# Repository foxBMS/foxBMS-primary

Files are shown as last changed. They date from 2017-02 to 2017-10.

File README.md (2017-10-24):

# foxBMS 

foxBMS is a free, open and flexible development environment to design battery
management systems. It is the first modular open source BMS development
platform.

## foxBMS Project Setup
The foxBMS project consists of several repositories.

The foxConda-installer repository contains the installer for the foxConda
environment. This environment provides all the tools necessary to generate the
documentation, compile the code for the MCUs and flash the generated binaries on
the MCUs (e.g., Python, git, GCC).

The starting point to get foxBMS is the foxBMS-setup
repository (https://github.com/foxBMS/foxBMS-setup), which contains
the general setup files for the foxBMS project. It includes a setup script
(bootstrap.py) which clones all the other needed repositories. The needed
documentation will be generated automatically after these repositories have been
cloned. The generated documentation is found in the directory ./build.
After the bootstrap step, the top project directory (foxBMS-setup) structure
looks like this:

 - foxBMS-setup <dir>
  - .git <dir> *
  - build <dir>
  - foxBMS-documentation <dir>
  - foxBMS-hardware <dir>
  - foxBMS-primary <dir>
  - foxBMS-secondary <dir>
  - foxBMS-tools <dir>
  - FreeRTOS <dir>
  - hal <dir>
  - .gitignore <file> *
  - bootstrap.py <file>
  - build.py <file>
  - CHANGELOG.md <file>
  - clean.py <file>
  - LICENSE.md <file>
  - README.md <file>
  - wscript <file>

* Directories and files with starting full stop are hidden in Windows in default
configuration.

There is a help available by running "python bootstrap.py -h".

## foxBMS Repositories

The foxConda-installer and foxBMS-setup repositories have already been described.

foxBMS is made out of two Microcontroller Units (MCU), named primary and
secondary. The C code for the primary MCU is found in the repository
foxBMS-primary (https://github.com/foxBMS/foxBMS-primary). The C code for the
secondary MCU is found in the repository foxBMS-secondary
(https://github.com/foxBMS/foxBMS-secondary). The Doxygen documentation is
generated from these sources into ./build/primary/doxygen/html and
./build/secondary/doxygen/html respectively. The main file is in both cases
index.html.

The layout and schematic files for the foxBMS hardware are found in the
foxBMS-hardware repository (https://github.com/foxBMS/foxBMS-hardware).

The Hardware Abstraction Layer (hal) for foxBMS is found in the hal-repository
(https://github.com/foxBMS/hal.) The real time operating system (FreeRTOS) for
foxBMS is found in the FreeRTOS-repository (https://github.com/foxBMS/FreeRTOS.)

The tools needed for foxBMS are in the foxBMS-tools-repository
(https://github.com/foxBMS/foxBMS-tools.)

The general documentation files for the foxBMS project are found in the
foxBMS-documentation repository
(https://github.com/foxBMS/foxBMS-documentation). The sphinx documentation is
found in foxBMS-documentation/doc/sphinx while the Doxygen documentation
configuration is found in foxBMS-documentation/doc/doxygen. The Doxygen
documentation itself is found in the software sources of the primary and
secondary microcontroller. The general documentation, rendered from the sphinx
sources is found in ./build/sphinx/foxBMS-documentation/doc/sphinx/html. The
main file is index.html

A generated version of the Sphinx documentation can be found at
http://foxbms.readthedocs.io/. It explains the structure of the
foxBMS hardware, how to install the foxConda environment and how to use foxConda
to compile and flash the sources.

## Building the Sources
For building the software, open a shell and type "python build.py -h". All
available build options will be displayed. The top build directory is ./build.

## Cleaning the ./build-Directory
For cleaning instructions open a shell and type "python clean.py -h". All
available cleaning options will be displayed.

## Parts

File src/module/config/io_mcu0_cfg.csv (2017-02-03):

Package Pin | PortXpinY | Signalname | Group | Comment | Interface
41 | PA1 | MCU_0_ADC_CH_4 | # ADCs
56 | PB0 | MCU_0_ADC_CH_2 | # ADCs
57 | PB1 | MCU_0_ADC_CH_3 | # ADCs
54 | PC4 | MCU_0_ADC_CH_0 | # ADCs
55 | PC5 | MCU_0_ADC_CH_1 | # ADCs
47 | PA3 | MCU_0_BENDER_PWM | # Bender
43 | PH2 | MCU_0_BENDER_SUPPLY_ENABLE | # Bender
46 | PH5 | MCU_0_BENDER_OK | # Bender
119 | PA8 | MCU_0_CONTACTOR_4_CONTROL | # Contactors' Controll and Feedback Pins
120 | PA9 | MCU_0_CONTACTOR_3_CONTROL | # Contactors' Controll and Feedback Pins
164 | PB6 | MCU_0_CONTACTOR_7_FEEDBACK | # Contactors' Controll and Feedback Pins
139 | PC10 | MCU_0_CONTACTOR_6_CONTROL | # Contactors' Controll and Feedback Pins
140 | PC11 | MCU_0_CONTACTOR_6_FEEDBACK | # Contactors' Controll and Feedback Pins
115 | PC6 | MCU_0_CONTACTOR_3_FEEDBACK | # Contactors' Controll and Feedback Pins
116 | PC7 | MCU_0_CONTACTOR_4_FEEDBACK | # Contactors' Controll and Feedback Pins
117 | PC8 | MCU_0_CONTACTOR_5_FEEDBACK | # Contactors' Controll and Feedback Pins
118 | PC9 | MCU_0_CONTACTOR_5_CONTROL | # Contactors' Controll and Feedback Pins
144 | PD2 | MCU_0_CONTACTOR_7_CONTROL | # Contactors' Controll and Feedback Pins
146 | PD4 | MCU_0_INTERLOCK_CONTROL | # Contactors' Controll and Feedback Pins
147 | PD5 | MCU_0_INTERLOCK_FEEDBACK | # Contactors' Controll and Feedback Pins
128 | PH13 | MCU_0_CONTACTOR_0_FEEDBACK | # Contactors' Controll and Feedback Pins
129 | PH14 | MCU_0_CONTACTOR_1_FEEDBACK | # Contactors' Controll and Feedback Pins
130 | PH15 | MCU_0_CONTACTOR_2_FEEDBACK | # Contactors' Controll and Feedback Pins
44 | PH3 | MCU_0_CONTACTOR_8_CONTROL | # Contactors' Controll and Feedback Pins
45 | PH4 | MCU_0_CONTACTOR_8_FEEDBACK | # Contactors' Controll and Feedback Pins
131 | PI0 | MCU_0_CONTACTOR_2_CONTROL | # Contactors' Controll and Feedback Pins
132 | PI1 | MCU_0_CONTACTOR_1_CONTROL | # Contactors' Controll and Feedback Pins
133 | PI2 | MCU_0_CONTACTOR_0_CONTROL | # Contactors' Controll and Feedback Pins
33 | PC1 | MCU_0_SDCARD_SUPPLY_CONTROL | # Data Storage SPI and Supply
155 | PG12 | MCU_0_DATA_STORAGE_SPI_MISO | # Data Storage SPI and Supply
156 | PG13 | MCU_0_DATA_STORAGE_SPI_SCK | # Data Storage SPI and Supply
157 | PG14 | MCU_0_DATA_STORAGE_SPI_MOSI | # Data Storage SPI and Supply
7 | PI8 | MCU_0_DATA_STORAGE_EEPROM_SPI_NSS | # Data Storage SPI and Supply
11 | PI9 | MCU_0_DATA_STORAGE_SCCARD_SPI_NSS | # Data Storage SPI and Supply
34 | PC2 | MCU_0_DEBUG_LED_1 | # Debug LEDs
35 | PC3 | MCU_0_DEBUG_LED_0 | # Debug LEDs
32 | PC0 | MCU_0_FMC_RAM_SDNWE | # Flexible Memory Controller
142 | PD0 | MCU_0_FMC_RAM_D2 | # Flexible Memory Controller
143 | PD1 | MCU_0_FMC_RAM_D3 | # Flexible Memory Controller
98 | PD10 | MCU_0_FMC_RAM_D15 | # Flexible Memory Controller
104 | PD14 | MCU_0_FMC_RAM_D0 | # Flexible Memory Controller
105 | PD15 | MCU_0_FMC_RAM_D1 | # Flexible Memory Controller
96 | PD8 | MCU_0_FMC_RAM_D13 | # Flexible Memory Controller
97 | PD9 | MCU_0_FMC_RAM_D14 | # Flexible Memory Controller
169 | PE0 | MCU_0_FMC_RAM_NBL0 | # Flexible Memory Controller
170 | PE1 | MCU_0_FMC_RAM_NBL1 | # Flexible Memory Controller
73 | PE10 | MCU_0_FMC_RAM_D7 | # Flexible Memory Controller
74 | PE11 | MCU_0_FMC_RAM_D8 | # Flexible Memory Controller
75 | PE12 | MCU_0_FMC_RAM_D9 | # Flexible Memory Controller
76 | PE13 | MCU_0_FMC_RAM_D10 | # Flexible Memory Controller
77 | PE14 | MCU_0_FMC_RAM_D11 | # Flexible Memory Controller
78 | PE15 | MCU_0_FMC_RAM_D12 | # Flexible Memory Controller
68 | PE7 | MCU_0_FMC_RAM_D4 | # Flexible Memory Controller
69 | PE8 | MCU_0_FMC_RAM_D5 | # Flexible Memory Controller
70 | PE9 | MCU_0_FMC_RAM_D6 | # Flexible Memory Controller
16 | PF0 | MCU_0_FMC_RAM_A0 | # Flexible Memory Controller
17 | PF1 | MCU_0_FMC_RAM_A1 | # Flexible Memory Controller
59 | PF11 | MCU_0_FMC_RAM_SDNRAS | # Flexible Memory Controller
60 | PF12 | MCU_0_FMC_RAM_A6 | # Flexible Memory Controller
63 | PF13 | MCU_0_FMC_RAM_A7 | # Flexible Memory Controller
64 | PF14 | MCU_0_FMC_RAM_A8 | # Flexible Memory Controller
65 | PF15 | MCU_0_FMC_RAM_A9 | # Flexible Memory Controller
18 | PF2 | MCU_0_FMC_RAM_A2 | # Flexible Memory Controller
19 | PF3 | MCU_0_FMC_RAM_A3 | # Flexible Memory Controller
20 | PF4 | MCU_0_FMC_RAM_A4 | # Flexible Memory Controller
21 | PF5 | MCU_0_FMC_RAM_A5 | # Flexible Memory Controller
66 | PG0 | MCU_0_FMC_RAM_A10 | # Flexible Memory Controller
67 | PG1 | MCU_0_FMC_RAM_A11 | # Flexible Memory Controller
160 | PG15 | MCU_0_FMC_RAM_SDNCAS | # Flexible Memory Controller
108 | PG4 | MCU_0_FMC_RAM_BA0 | # Flexible Memory Controller
109 | PG5 | MCU_0_FMC_RAM_BA1 | # Flexible Memory Controller
112 | PG8 | MCU_0_FMC_RAM_SDCLK | # Flexible Memory Controller
83 | PH6 | MCU_0_FMC_RAM_SDNE1 | # Flexible Memory Controller
84 | PH7 | MCU_0_FMC_RAM_SDCKE1 | # Flexible Memory Controller
14 | GND |  | # Ground Pins
22 | GND |  | # Ground Pins
61 | GND |  | # Ground Pins
71 | GND |  | # Ground Pins
90 | GND |  | # Ground Pins
102 | GND |  | # Ground Pins
113 | GND |  | # Ground Pins
126 | GND |  | # Ground Pins
135 | GND |  | # Ground Pins
148 | GND |  | # Ground Pins
158 | GND |  | # Ground Pins
121 | PA10 | MCU_0_BMS_INTERFACE_GPIO_0 | # Interfaces
122 | PA11 | MCU_0_BMS_INTERFACE_GPIO_1 | # Interfaces
123 | PA12 | MCU_0_BMS_INTERFACE_GPIO_2 | # Interfaces
42 | PA2 | MCU_0_RS485_TX | # Interfaces
50 | PA4 | MCU_0_BMS_INTERFACE_SPI_NSS | # Interfaces
51 | PA5 | MCU_0_BMS_INTERFACE_SPI_SCK | # Interfaces
52 | PA6 | MCU_0_BMS_INTERFACE_SPI_MISO | # Interfaces
53 | PA7 | MCU_0_BMS_INTERFACE_SPI_MOSI | # Interfaces
79 | PB10 | MCU_0_FTDI_TX | # Interfaces
80 | PB11 | MCU_0_FTDI_RX | # Interfaces
92 | PB12 | MCU_0_TO_MCU_1_INTERFACE_SPI_NSS | # Interfaces
93 | PB13 | MCU_0_CAN_0_TX | # Interfaces | CAN bootable (CAN2)
94 | PB14 | MCU_0_TO_MCU_1_INTERFACE_SPI_MISO | # Interfaces
95 | PB15 | MCU_0_TO_MCU_1_INTERFACE_SPI_MOSI | # Interfaces
162 | PB4 | MCU_0_BMS_INTERFACE_GPIO_3 | # Interfaces
163 | PB5 | MCU_0_CAN_0_RX | # Interfaces
165 | PB7 | MCU_0_CAN_1_TRANS_STANDBY_CONTROL | # Interfaces
167 | PB8 | MCU_0_CAN_1_RX | # Interfaces
168 | PB9 | MCU_0_CAN_1_TX | # Interfaces
141 | PC12 | MCU_0_CAN_0_TRANS_STANDBY_CONTROL | # Interfaces
145 | PD3 | MCU_0_TO_MCU_1_INTERFACE_SPI_SCK | # Interfaces
150 | PD6 | MCU_0_RS845_RX | # Interfaces
24 | PF6 | MCU_0_TO_FPGA_INTERFACE_SPI_NSS | # Interfaces
25 | PF7 | MCU_0_TO_FPGA_INTERFACE_SPI_SCK | # Interfaces
26 | PF8 | MCU_0_TO_FPGA_INTERFACE_SPI_MISO | # Interfaces
27 | PF9 | MCU_0_TO_FPGA_INTERFACE_SPI_MOSI | # Interfaces
106 | PG2 | MCU_0_RS485_NRE | # Interfaces
107 | PG3 | MCU_0_RS485_DE | # Interfaces
99 | PD11 | MCU_0_ISONOC_5_CONTROL | # Isolated In- and Outputs
100 | PD12 | MCU_0_ISO_GPIO_OUT_0 | # Isolated In- and Outputs
101 | PD13 | MCU_0_ISO_GPIO_OUT_1 | # Isolated In- and Outputs
153 | PG10 | MCU_0_ISO_GPIO_IN_1 | # Isolated In- and Outputs
154 | PG11 | MCU_0_ISO_GPIO_OUT_2 | # Isolated In- and Outputs
152 | PG9 | MCU_0_ISO_GPIO_IN_0 | # Isolated In- and Outputs
87 | PH10 | MCU_0_ISONOC_2_CONTROL | # Isolated In- and Outputs
88 | PH11 | MCU_0_ISONOC_3_CONTROL | # Isolated In- and Outputs
89 | PH12 | MCU_0_ISONOC_4_CONTROL | # Isolated In- and Outputs
85 | PH8 | MCU_0_ISONOC_0_CONTROL | # Isolated In- and Outputs
86 | PH9 | MCU_0_ISONOC_1_CONTROL | # Isolated In- and Outputs
173 | PI4 | MCU_0_ISO_GPIO_OUT_3 | # Isolated In- and Outputs
174 | PI5 | MCU_0_ISO_GPIO_IN_2 | # Isolated In- and Outputs
175 | PI6 | MCU_0_ISO_GPIO_IN_3 | # Isolated In- and Outputs
8 | PC13 | MCU_0_RTC_ALARM_OUT | # Pins free to be used
151 | PD7 |  | # Pins free to be used
28 | PF10 |  | # Pins free to be used
110 | PG6 |  | # Pins free to be used
111 | PG7 |  | # Pins free to be used
12 | PI10 |  | # Pins free to be used
13 | PI11 |  | # Pins free to be used
134 | PI3 |  | # Pins free to be used
176 | PI7 |  | # Pins free to be used
166 | BOOT0 |  | # Special Pins | Boot0
48 | BYPASS_REG |  | # Special Pins | BYPASS_REG
37 | GNDA |  | # Special Pins | GNDA
31 | NRST |  | # Special Pins | RESET
40 | PA0 |  | # Special Pins | Wakeup
124 | PA13 |  | # Special Pins | SWDIO
137 | PA14 |  | # Special Pins | SWCLK
138 | PA15 |  | # Special Pins | TDI
58 | PB2 |  | # Special Pins | BOOT1
161 | PB3 |  | # Special Pins | SWO
9 | PC14 |  | # Special Pins | RTC_XTAL
10 | PC15 |  | # Special Pins | RTC_XTAL
171 | PDR_ON |  | # Special Pins | PDR_ON
29 | PH0 |  | # Special Pins | XTAL
30 | PH1 |  | # Special Pins | XTAL
6 | VBATT |  | # Special Pins | Battery
81 | VCAP_1 |  | # Special Pins | VCAP_1
125 | VCAP_2 |  | # Special Pins | VCAP_2
39 | VCCA |  | # Special Pins | VCCA
38 | VREF+ |  | # Special Pins | VREF 2.5V
15 | VCC |  | # Supply Pins
23 | VCC |  | # Supply Pins
36 | VCC |  | # Supply Pins
49 | VCC |  | # Supply Pins
62 | VCC |  | # Supply Pins
72 | VCC |  | # Supply Pins
82 | VCC |  | # Supply Pins
91 | VCC |  | # Supply Pins
103 | VCC |  | # Supply Pins
114 | VCC |  | # Supply Pins
127 | VCC |  | # Supply Pins
136 | VCC |  | # Supply Pins
149 | VCC |  | # Supply Pins
159 | VCC |  | # Supply Pins
172 | VCC |  | # Supply Pins
1 | PE2 | MCU_0_TRACECLK | # Trace
2 | PE3 | MCU_0_TRACED0 | # Trace
3 | PE4 | MCU_0_TRACED1 | # Trace
4 | PE5 | MCU_0_TRACED2 | # Trace
5 | PE6 | MCU_0_TRACED3 | # Trace

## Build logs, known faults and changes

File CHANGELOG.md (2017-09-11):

# foxBMS Change Log

## Release 0.5.2

Release notes:
We fixed a bug in the ltc driver, leading to a non-functional temperature 
sensing for foxBMS Slave Hardware version 1.xx. The slave version is 
configuration for the primary MCU in foxBMS-primary\src\module\config\ltc_cfg.h
by the define SLAVE_BOARD_VERSION and for the secondary MCU in 
foxBMS-secondary\src\module\config\ltc_cfg.h by the define SLAVE_BOARD_VERSION.
 - Set SLAVE_BOARD_VERSION to "1" if you are using version 1.xx of the foxBMS 
   Slave.
 - Set SLAVE_BOARD_VERSION to "2" if you are using version 2.xx of the foxBMS 
   Slave. Version 2.xx is the default configuration.

Changelog :
- foxBMS-primary
  - fixed LTC temperature sensing bug
- foxBMS-secondary
  - fixed LTC temperature sensing bug

## Release 0.5.1

- foxBMS-setup
  - added parameter '-u', '--update' to bootstrap.py for updating the setup
    repository.
- foxBMS-primary
  - updates for waf 1.9.13 support
  - updated module/EEPROM and migrated to module/nvmram
  - minor code adaptations and cleanup
- foxBMS-secondary
  - support for waf 1.9.13
  - minor code adaptations and cleanup
- foxbMS-tools
  - updated waf from version 1.8.12 to version 1.9.13

## Release 0.5.0

A new project structure is now used by foxBMS. The documentation is no more
contained in the embedded software sources and has its own repository. FreeRTOS
and hal have their own repository, too.
A central repository called foxBMS-setup is now used. It contains
several scripts:
 - bootstrap.py gets all the repositories needed to work with foxBMS
 - build.py is used to compile binaries and to generate the documentation
 - clean.py is used to removed the generated binaries and documentation

Release notes:

 - New project structure

 - Added support for external (SPI) EEPROM on the BMS-Master
 - Redesign of can and cansignal module to simplify the usage
 - Added support for triggered and cyclic current measurement of Isabellenhütte
   current sensor (IVT)
 - Current sensor now functions by default in non-triggered modus (no
   reprogramming needed for the sensor)

 - Updated and restructured complete documentation
 - Restructured file and folder structure for the documentation
 - Added safety and risk analysis section
 - Cleaning up of non-used files in the documentation
 - Consistency check and correction of the naming and wording used
 - Addition of the source files (e.g., Microsoft Visio diagrams) used to
   generate the figures in the documentation
 - Reformatted the licenses text formatting (no changes in the licenses
   content)
 - Updated the battery junction box (BJB) section with up-to-date components
   and parameters

## Release 0.4.4

The checksum tool is now automatically called when building binaries.
Therefore the command
    python tools/waf-1.8.12 configure build chksum
is NOT longer supported. The command to build binaries with checksum support is
    python tools/waf-1.8.12 configure build
This is the build command used in foxBMS FrontDesk, that is, FrontDesk software
is compatible with this change and now supports automatic checksum builds.

Release notes:
 - Improved checksum-feature
 - Updated copyright 2010 - 2017

## Release 0.4.3

Starting from this version, a checksum mechanism was implemented in foxBMS. If
the checksum is active and it is not computed correctly, it will prevent the
flashed program from running. Details on deactivating the checksum can be found
in the Software FAQ, in How to use and deactivate the checksum.

Release notes:
 - Important: Changed contactor configuration order in the software to match
   the labels on the front
  - Contactor 0: CONT_PLUS_MAIN
  - Contactor 1: CONT_PLUS_PRECHARGE
  - Contactor 2: CONT_MINUS_MAIN
 - Fixed an bug which could cause an unintended closing of the contactors after
   recovering from error mode
 - Increased stack size for the engine tasks to avoid stack overflow in some
   special conditions
 - Added a note in the documentation to indicate the necessity to send a
   periodic CAN message to the BMS
 - Fixed DLC of CAN message for the current sensor measurement
 - Added checksum verification for the flashed binaries
 - Updated linker script to allow integration of the checksum tool
 - Activated debug without JTAG interface via USB

## Release 0.4.2

Release notes:
 - Removed schematic files from documentation, registration needed to obtain
   the files
 - Added entries to the software FAQ

## Release 0.4.1

Release notes:

 - Corrected daisy chain connector pinout in quickstart guide
 - Corrected code for contactors, to allow using contactors without feedback
 - Corrected LTC code for reading balancing feedback
 - Quickstart restructured, with mention of the necessity to generate the HTML
   documentation

## Release 0.4.0

Beta version of foxBS that was supplied to selected partners for evaluation.

Release notes:

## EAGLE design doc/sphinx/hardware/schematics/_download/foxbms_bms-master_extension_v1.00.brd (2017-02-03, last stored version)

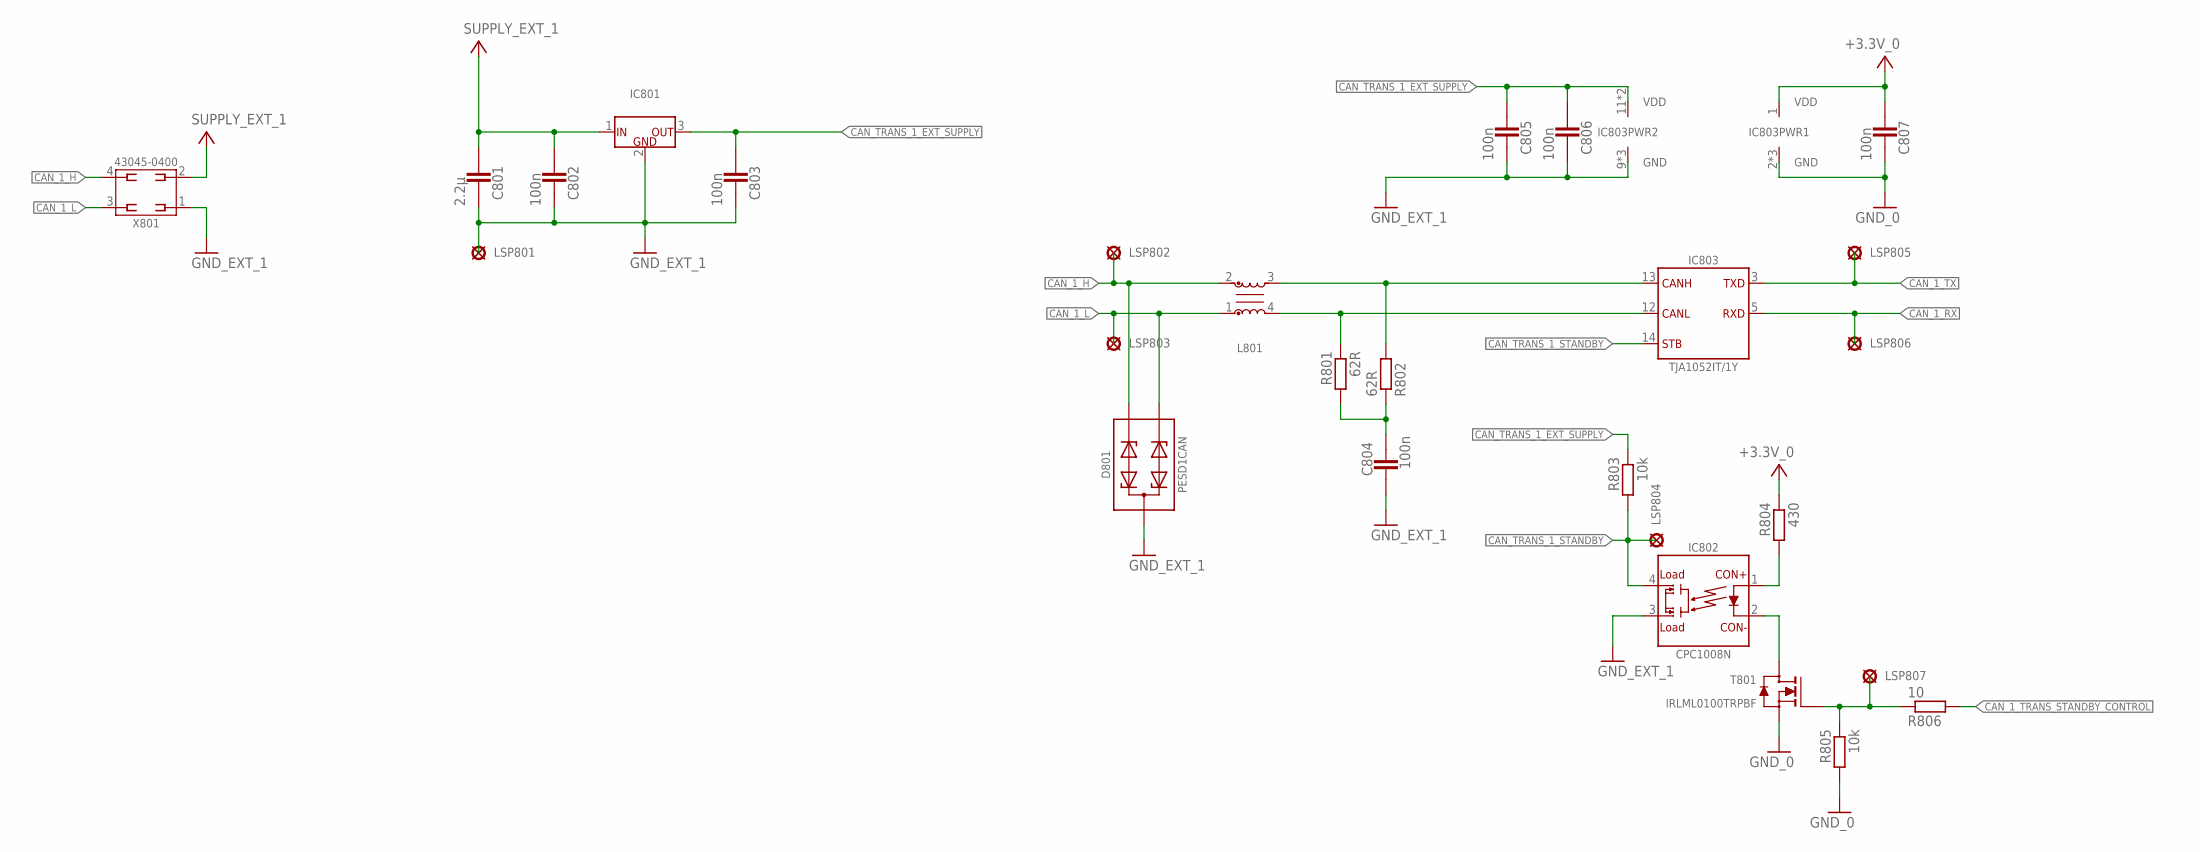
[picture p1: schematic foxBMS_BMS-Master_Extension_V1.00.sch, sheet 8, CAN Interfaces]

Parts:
C801: 2.2µ; 0603
C802, C803, C804, C805, C806, C807: 100n; 0603
D801: PESD1CAN; D_SMD_SOT23_(TO-236AB)_R_NXP_REV01
IC801: KA7805ERTF; IC_SMD_TO-252_(D-PAK)_R_FAIRCHILD_REV01
IC802: CPC1008N; K_SMD_SOP-4_R_IXYS_REV01
IC803: TJA1052IT/1Y; IC_SMD_SO16_(SOT162-1)_R_NXP_REV01
L801: B82789C0513N002; L_SMD_FILTER_HF_R_EPCOS_SIMDAD_1812_REV01
LSP801, LSP802, LSP803, LSP804, LSP805, LSP806, LSP807: PAD_2.0X1.5MM; PAD2.0X1.5MM
R801, R802: 62R; 0603
R803, R805: 10k; 0603
R804: 430; 0603
R806: 10; 0603
T801: IRLML0100TRPBF; V_SMD_SOT-23_(TO-236AB)_R_IR_REV01
X801: 43045-0400_MOLEX_4PIN; X_TH_MOLEX_43045-0400_R_REV01

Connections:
+3.3V_0: C807.2, IC803.1 (VDD), R804.1; also elsewhere on the board
CAN_1_H: D801.1, L801.2, LSP802.P$1, X801.4
CAN_1_L: D801.2, L801.1, LSP803.P$1, X801.3
CAN_1_RX: IC803.5 (RXD), LSP806.P$1; also elsewhere on the board
CAN_1_TRANS_STANDBY_CONTROL: R806.2; also elsewhere on the board
CAN_1_TX: IC803.3 (TXD), LSP805.P$1; also elsewhere on the board
CAN_L_INT1: IC803.12 (CANL), L801.4, R801.1
CAN_SPLIT1: C804.1, R801.2, R802.1
CAN_TRANS_1_EXT_SUPPLY: C803.2, C805.2, C806.2, IC801.3 (OUT), IC803.11 (VDD), IC803.16 (VDD), R803.1
CAN_TRANS_1_STANDBY: IC802.4, IC803.14 (STB), LSP804.P$1, R803.2
GND_0: C807.1, IC803.2 (GND), IC803.7 (GND), IC803.8 (GND), R805.2, T801.2 (S); also elsewhere on the board
GND_EXT_1: C801.1, C802.1, C803.1, C804.2, C805.1, C806.1, D801.3, IC801.2 (GND), IC802.3, IC803.9 (GND), IC803.10 (GND), IC803.15 (GND), LSP801.P$1, X801.1
unnamed: IC803.13 (CANH), L801.3, R802.2
unnamed: IC802.2 (CON-), T801.3 (D)
unnamed: IC802.1 (CON+), R804.2
unnamed: LSP807.P$1, R805.1, R806.1, T801.1 (G)
SUPPLY_EXT_1: C801.2, C802.2, IC801.1 (IN), X801.2

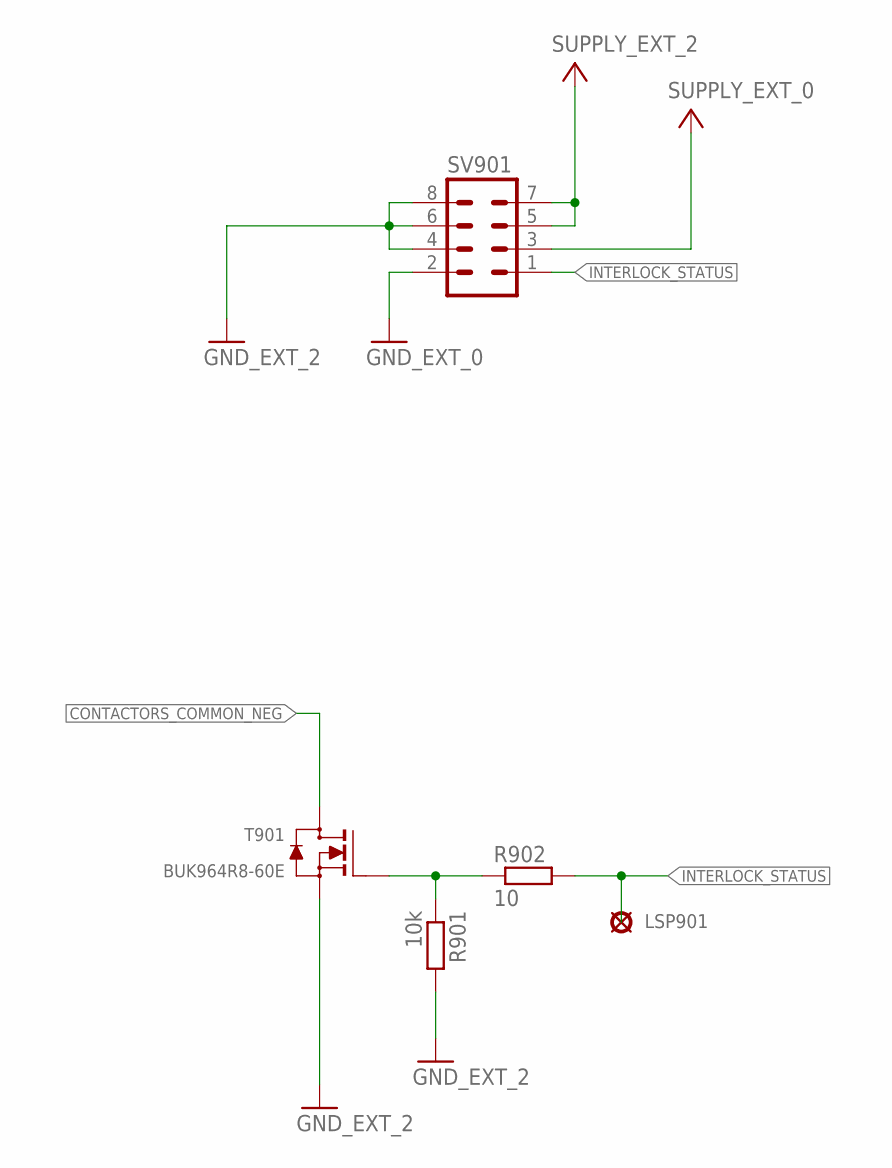
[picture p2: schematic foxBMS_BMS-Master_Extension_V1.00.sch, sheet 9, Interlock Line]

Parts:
LSP901: PAD_2.0X1.5MM; PAD2.0X1.5MM
R901: 10k; 0603
R902: 10; 0603
SV901: MA04-2
T901: BUK964R8-60E; V_SMD_TO-263_(D²PAK)_R_NXP_REV01

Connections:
CONTACTORS_COMMON_NEG: T901.2 (D); also elsewhere on the board
GND_EXT_0: SV901.2; also elsewhere on the board
GND_EXT_2: R901.2, SV901.4, SV901.6, SV901.8, T901.3 (S); also elsewhere on the board
INTERLOCK_STATUS: LSP901.P$1, R902.2, SV901.1
unnamed: R901.1, R902.1, T901.1 (G)
SUPPLY_EXT_0: SV901.3; also elsewhere on the board
SUPPLY_EXT_2: SV901.5, SV901.7; also elsewhere on the board

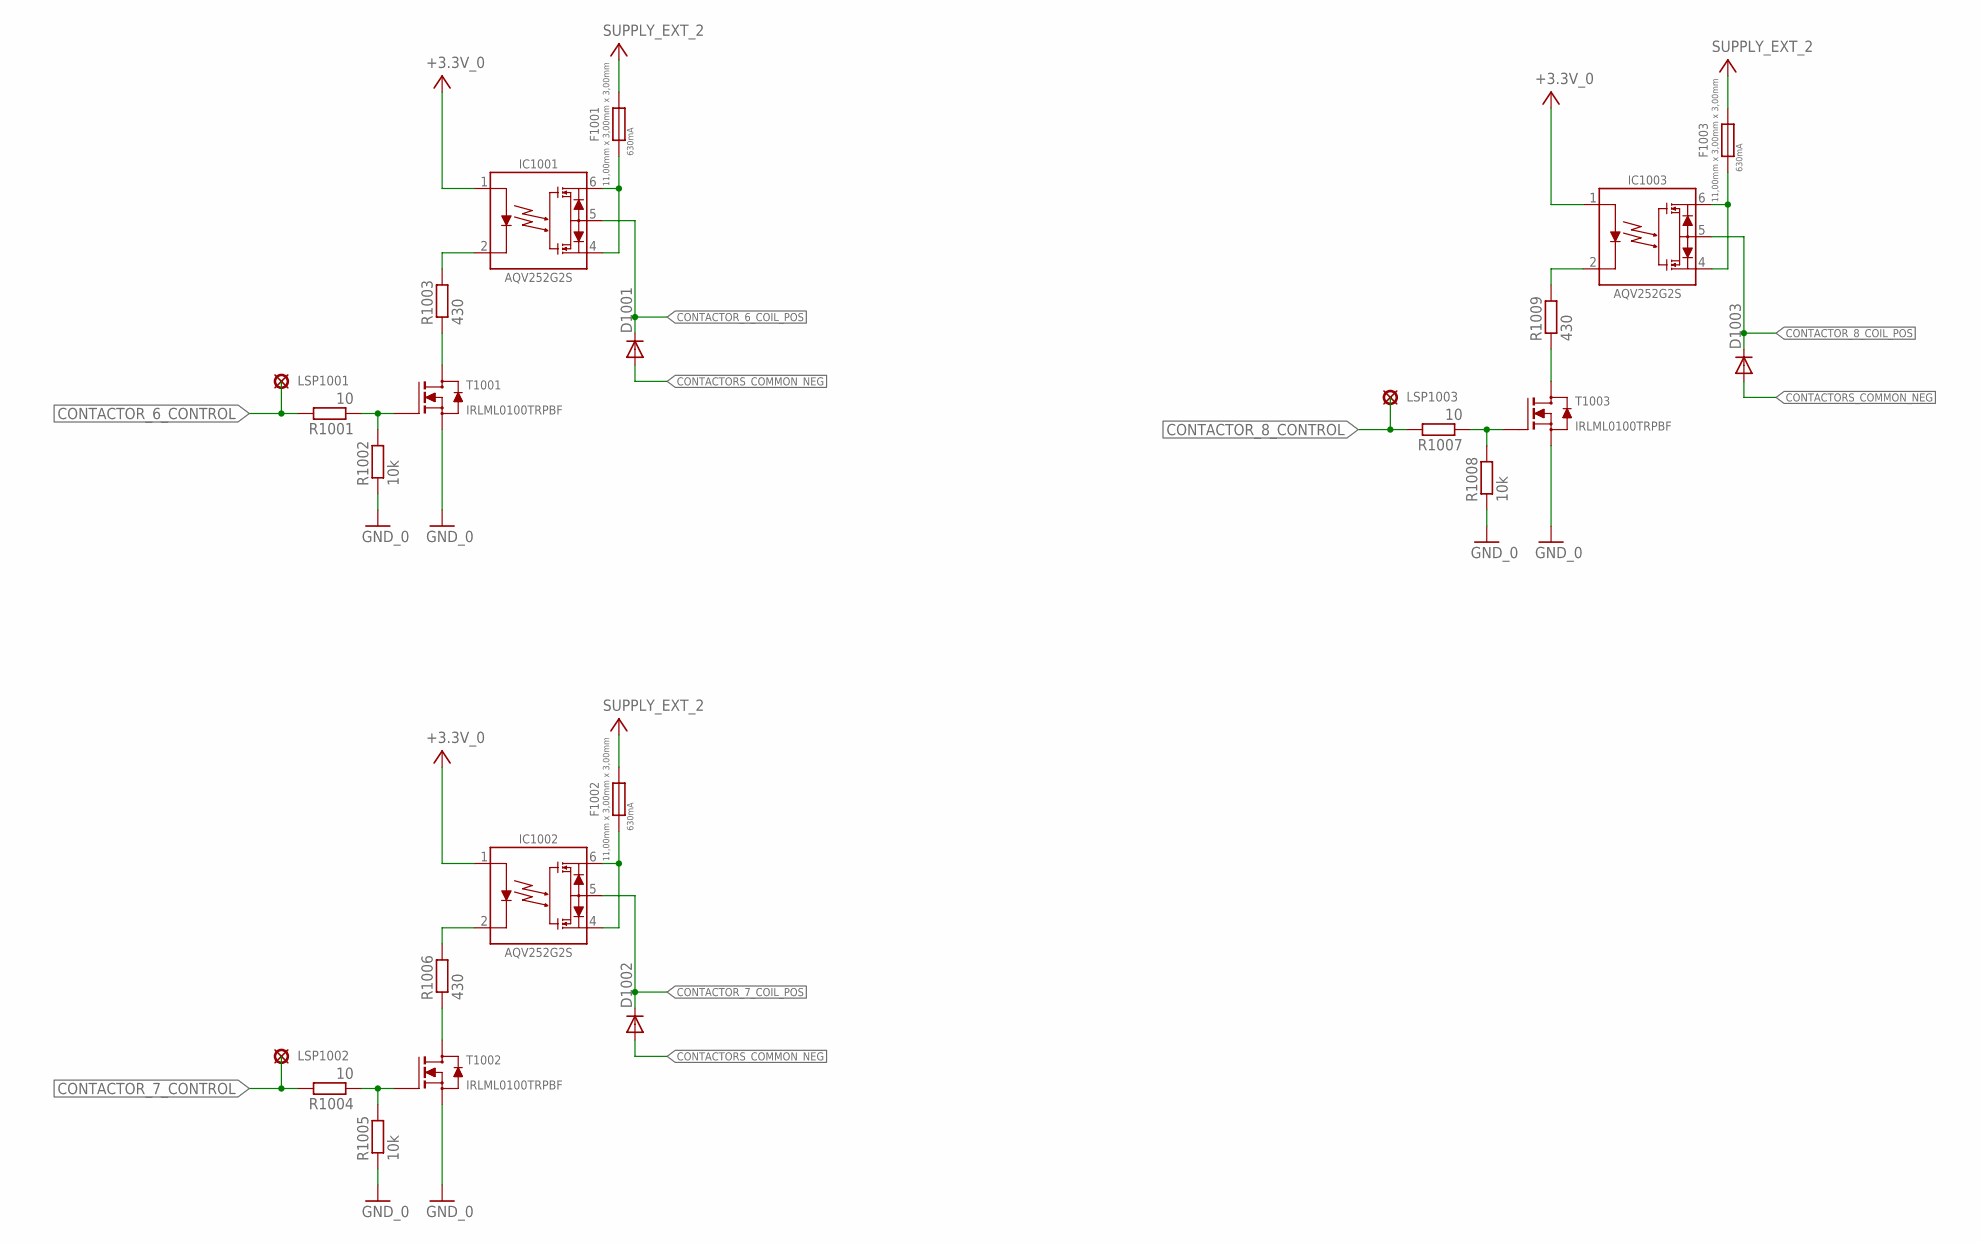
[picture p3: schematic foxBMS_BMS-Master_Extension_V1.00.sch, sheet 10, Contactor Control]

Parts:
D1001, D1002, D1003: DIODE-DO214BA; DO214BA
F1001, F1002, F1003: 630MA_UMT; F_SMD_11,00MMX3,00MMX3,00MM_(UMT)_R_SCHURTER_REV01
IC1001, IC1002, IC1003: AQV252G2S; K_SMD_SOP-6_R_PANASONIC_REV01
LSP1001, LSP1002, LSP1003: PAD_2.0X1.5MM; PAD2.0X1.5MM
R1001, R1004, R1007: 10; 0603
R1002, R1005, R1008: 10k; 0603
R1003, R1006, R1009: 430; 0603
T1001, T1002, T1003: IRLML0100TRPBF; V_SMD_SOT-23_(TO-236AB)_R_IR_REV01

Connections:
+3.3V_0: IC1001.1, IC1002.1, IC1003.1; also elsewhere on the board
CONTACTORS_COMMON_NEG: D1001.A, D1002.A, D1003.A; also elsewhere on the board
CONTACTOR_6_COIL_POS: D1001.C, IC1001.5; also elsewhere on the board
CONTACTOR_6_CONTROL: LSP1001.P$1, R1001.2; also elsewhere on the board
CONTACTOR_7_COIL_POS: D1002.C, IC1002.5; also elsewhere on the board
CONTACTOR_7_CONTROL: LSP1002.P$1, R1004.2; also elsewhere on the board
CONTACTOR_8_COIL_POS: D1003.C, IC1003.5; also elsewhere on the board
CONTACTOR_8_CONTROL: LSP1003.P$1, R1007.2; also elsewhere on the board
GND_0: R1002.1, R1005.1, R1008.1, T1001.2 (S), T1002.2 (S), T1003.2 (S); also elsewhere on the board
unnamed: R1003.1, T1001.3 (D)
unnamed: R1006.1, T1002.3 (D)
unnamed: R1009.1, T1003.3 (D)
unnamed: F1001.1, IC1001.4, IC1001.6
unnamed: F1002.1, IC1002.4, IC1002.6
unnamed: F1003.1, IC1003.4, IC1003.6
unnamed: IC1001.2, R1003.2
unnamed: R1001.1, R1002.2, T1001.1 (G)
unnamed: IC1002.2, R1006.2
unnamed: R1004.1, R1005.2, T1002.1 (G)
unnamed: IC1003.2, R1009.2
unnamed: R1007.1, R1008.2, T1003.1 (G)
SUPPLY_EXT_2: F1001.2, F1002.2, F1003.2; also elsewhere on the board

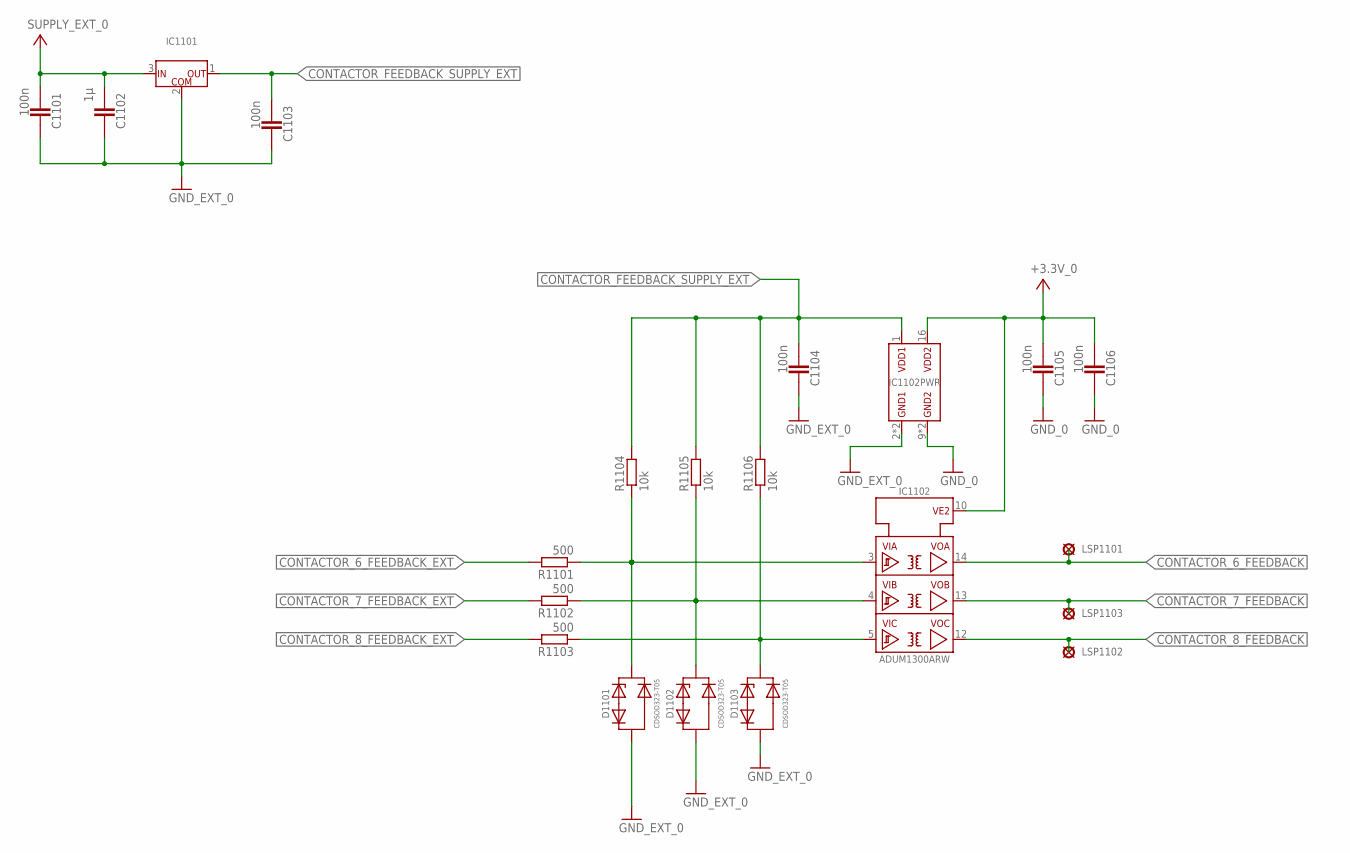
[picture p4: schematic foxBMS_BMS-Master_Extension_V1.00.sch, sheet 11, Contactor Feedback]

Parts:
C1101, C1103, C1104, C1105, C1106: 100n; 0603
C1102: 1µ; 0603
D1101, D1102, D1103: CDSOD323-T05; D_SMD_SOD323_(SC-76)_R_BOURNS_REV01
IC1101: UA78L05ACPK; IC_SMD_SOT-89_(SC-62/TO-243)_(R-PSSO-F3)_R_TI_REV01
IC1102: ADUM1300ARW; IC_SMD_SOIC-16_(JEDEC_MS-013-AA)_R_ANALOG_REV01
LSP1101, LSP1102, LSP1103: PAD_2.0X1.5MM; PAD2.0X1.5MM
R1101, R1102, R1103: 500; 0603
R1104, R1105, R1106: 10k; 0603

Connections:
+3.3V_0: C1105.1, C1106.1, IC1102.10 (VE2), IC1102.16 (VDD2); also elsewhere on the board
CONTACTOR_6_FEEDBACK: IC1102.14 (VOA), LSP1101.P$1; also elsewhere on the board
CONTACTOR_6_FEEDBACK_EXT: R1101.2; also elsewhere on the board
CONTACTOR_7_FEEDBACK: IC1102.13 (VOB), LSP1103.P$1; also elsewhere on the board
CONTACTOR_7_FEEDBACK_EXT: R1102.2; also elsewhere on the board
CONTACTOR_8_FEEDBACK: IC1102.12 (VOC), LSP1102.P$1; also elsewhere on the board
CONTACTOR_8_FEEDBACK_EXT: R1103.2; also elsewhere on the board
CONTACTOR_FEEDBACK_SUPPLY_EXT: C1103.1, C1104.1, IC1101.1 (OUT), IC1102.1 (VDD1), R1104.2, R1105.2, R1106.2
GND_0: C1105.2, C1106.2, IC1102.9 (GND2), IC1102.15 (GND2); also elsewhere on the board
GND_EXT_0: C1101.2, C1102.2, C1103.2, C1104.2, D1101.A, D1102.A, D1103.A, IC1101.2 (COM), IC1102.2 (GND1), IC1102.8 (GND1); also elsewhere on the board
unnamed: D1101.C, IC1102.3 (VIA), R1101.1, R1104.1
unnamed: D1102.C, IC1102.4 (VIB), R1102.1, R1105.1
unnamed: D1103.C, IC1102.5 (VIC), R1103.1, R1106.1
SUPPLY_EXT_0: C1101.1, C1102.1, IC1101.3 (IN); also elsewhere on the board

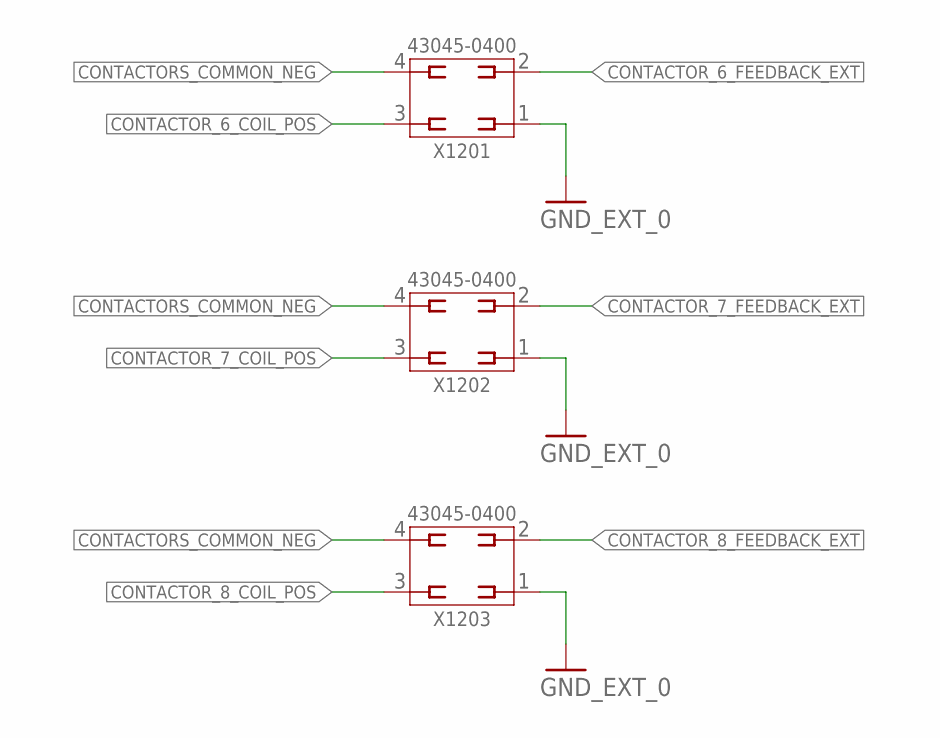
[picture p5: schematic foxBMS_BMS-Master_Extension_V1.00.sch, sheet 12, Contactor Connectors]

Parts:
X1201, X1202, X1203: 43045-0400_MOLEX_4PIN; X_TH_MOLEX_43045-0400_R_REV01

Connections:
CONTACTORS_COMMON_NEG: X1201.4, X1202.4, X1203.4; also elsewhere on the board
CONTACTOR_6_COIL_POS: X1201.3; also elsewhere on the board
CONTACTOR_6_FEEDBACK_EXT: X1201.2; also elsewhere on the board
CONTACTOR_7_COIL_POS: X1202.3; also elsewhere on the board
CONTACTOR_7_FEEDBACK_EXT: X1202.2; also elsewhere on the board
CONTACTOR_8_COIL_POS: X1203.3; also elsewhere on the board
CONTACTOR_8_FEEDBACK_EXT: X1203.2; also elsewhere on the board
GND_EXT_0: X1201.1, X1202.1, X1203.1; also elsewhere on the board

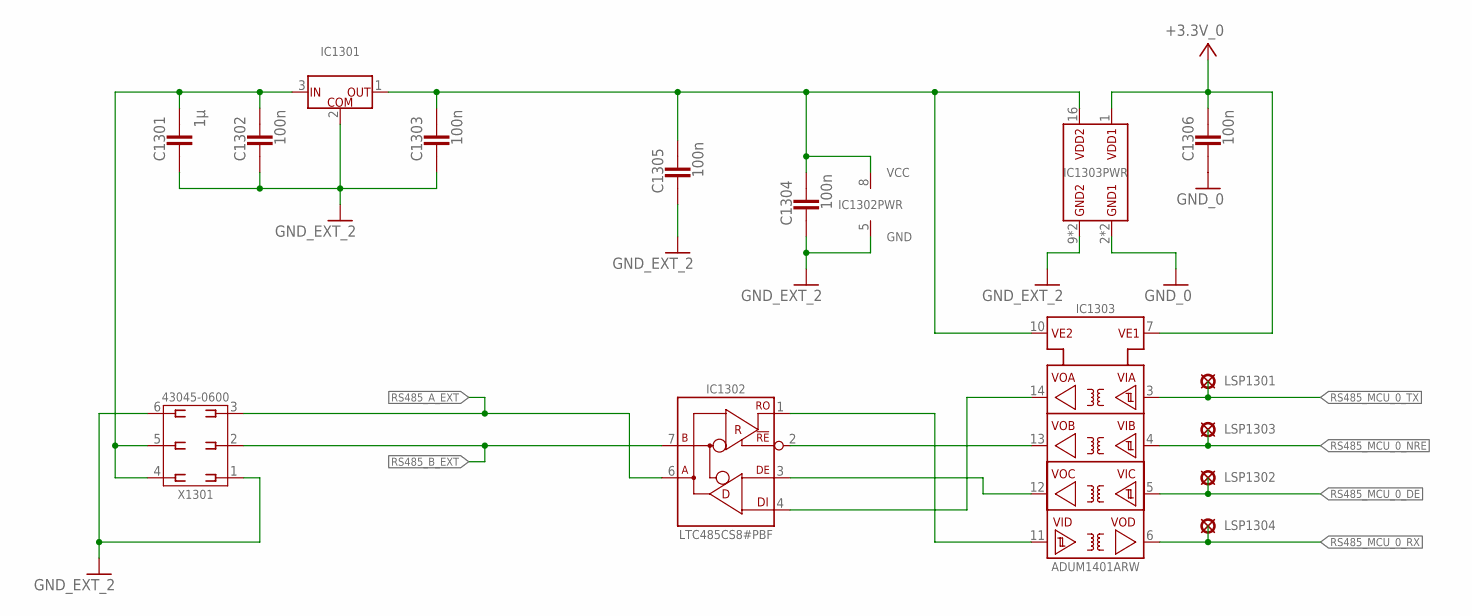
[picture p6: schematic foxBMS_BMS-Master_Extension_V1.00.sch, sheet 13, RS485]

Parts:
C1301: 1µ; 0603
C1302, C1303, C1304, C1305, C1306: 100n; 0603
IC1301: UA78L05ACPK; IC_SMD_SOT-89_(SC-62/TO-243)_(R-PSSO-F3)_R_TI_REV01
IC1302: LTC485CS8#PBF; IC_SMD_SOIC-8_(S8_REV_G)_R_LINEAR_REV01
IC1303: ADUM1401ARW; IC_SMD_SOIC-16_(JEDEC_MS-013-AA)_R_ANALOG_REV01
LSP1301, LSP1302, LSP1303, LSP1304: PAD_2.0X1.5MM; PAD2.0X1.5MM
X1301: 43045-0600_MOLEX_6PIN; X_TH_MOLEX_43045-0600_R_REV01

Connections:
+3.3V_0: C1306.1, IC1303.1 (VDD1), IC1303.7 (VE1); also elsewhere on the board
GND_0: C1306.2, IC1303.2 (GND1), IC1303.8 (GND1); also elsewhere on the board
GND_EXT_2: C1301.2, C1302.2, C1303.2, C1304.2, C1305.2, IC1301.2 (COM), IC1302.5 (GND), IC1303.9 (GND2), IC1303.15 (GND2), X1301.1, X1301.6; also elsewhere on the board
unnamed: C1301.1, C1302.1, IC1301.3 (IN), X1301.4, X1301.5
unnamed: IC1302.1 (RO), IC1303.11 (VID)
unnamed: IC1302.2 (!RE), IC1303.13 (VOB)
unnamed: IC1302.3 (DE), IC1303.12 (VOC)
unnamed: IC1302.4 (DI), IC1303.14 (VOA)
unnamed: C1303.1, C1304.1, C1305.1, IC1301.1 (OUT), IC1302.8 (VCC), IC1303.10 (VE2), IC1303.16 (VDD2)
RS485_A_EXT: IC1302.6 (A), X1301.3
RS485_B_EXT: IC1302.7 (B), X1301.2
RS485_MCU_0_DE: IC1303.5 (VIC), LSP1302.P$1; also elsewhere on the board
RS485_MCU_0_NRE: IC1303.4 (VIB), LSP1303.P$1; also elsewhere on the board
RS485_MCU_0_RX: IC1303.6 (VOD), LSP1304.P$1; also elsewhere on the board
RS485_MCU_0_TX: IC1303.3 (VIA), LSP1301.P$1; also elsewhere on the board

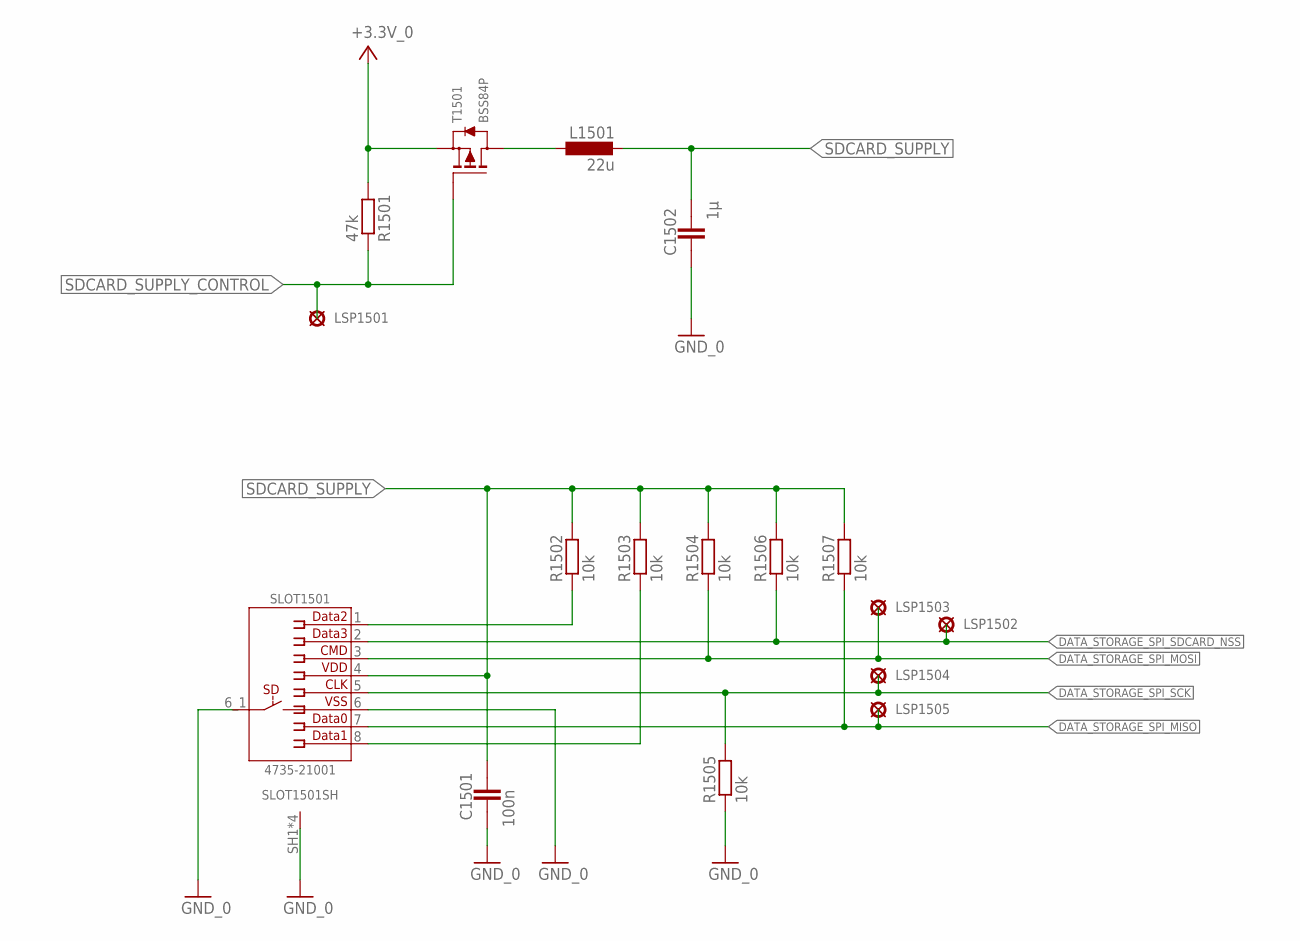
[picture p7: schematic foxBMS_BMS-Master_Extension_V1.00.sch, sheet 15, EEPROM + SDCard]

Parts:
C1501: 100n; 0603
C1502: 1µ; 0603
L1501: 22u; 0805
LSP1501, LSP1502, LSP1503, LSP1504, LSP1505: PAD_2.0X1.5MM; PAD2.0X1.5MM
R1501: 47k; 0603
R1502, R1503, R1504, R1505, R1506, R1507: 10k; 0603
SLOT1501: MICRO_SD; X_SMD_MICRO-SD-4735-21001_R_MOLEX_REV01
T1501: BSS84P; V_SMD_SOT23_(TO-236AB)_R_INFINEON_REV01

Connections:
+3.3V_0: R1501.2, T1501.2 (S); also elsewhere on the board
DATA_STORAGE_SPI_MISO: LSP1505.P$1, R1507.1, SLOT1501.7; also elsewhere on the board
DATA_STORAGE_SPI_MOSI: LSP1503.P$1, R1504.1, SLOT1501.3; also elsewhere on the board
DATA_STORAGE_SPI_SCK: LSP1504.P$1, R1505.2, SLOT1501.5; also elsewhere on the board
DATA_STORAGE_SPI_SDCARD_NSS: LSP1502.P$1, R1506.1, SLOT1501.2; also elsewhere on the board
GND_0: C1501.1, C1502.2, R1505.1, SLOT1501.6, SLOT1501.6_1 (9), SLOT1501.SH1 (SH), SLOT1501.SH2 (SH), SLOT1501.SH3 (SH), SLOT1501.SH5 (SH); also elsewhere on the board
unnamed: L1501.2, T1501.3 (D)
unnamed: R1502.1, SLOT1501.1
unnamed: R1503.1, SLOT1501.8
SDCARD_SUPPLY: C1501.2, C1502.1, L1501.1, R1502.2, R1503.2, R1504.2, R1506.2, R1507.2, SLOT1501.4
SDCARD_SUPPLY_CONTROL: LSP1501.P$1, R1501.1, T1501.1 (G); also elsewhere on the board

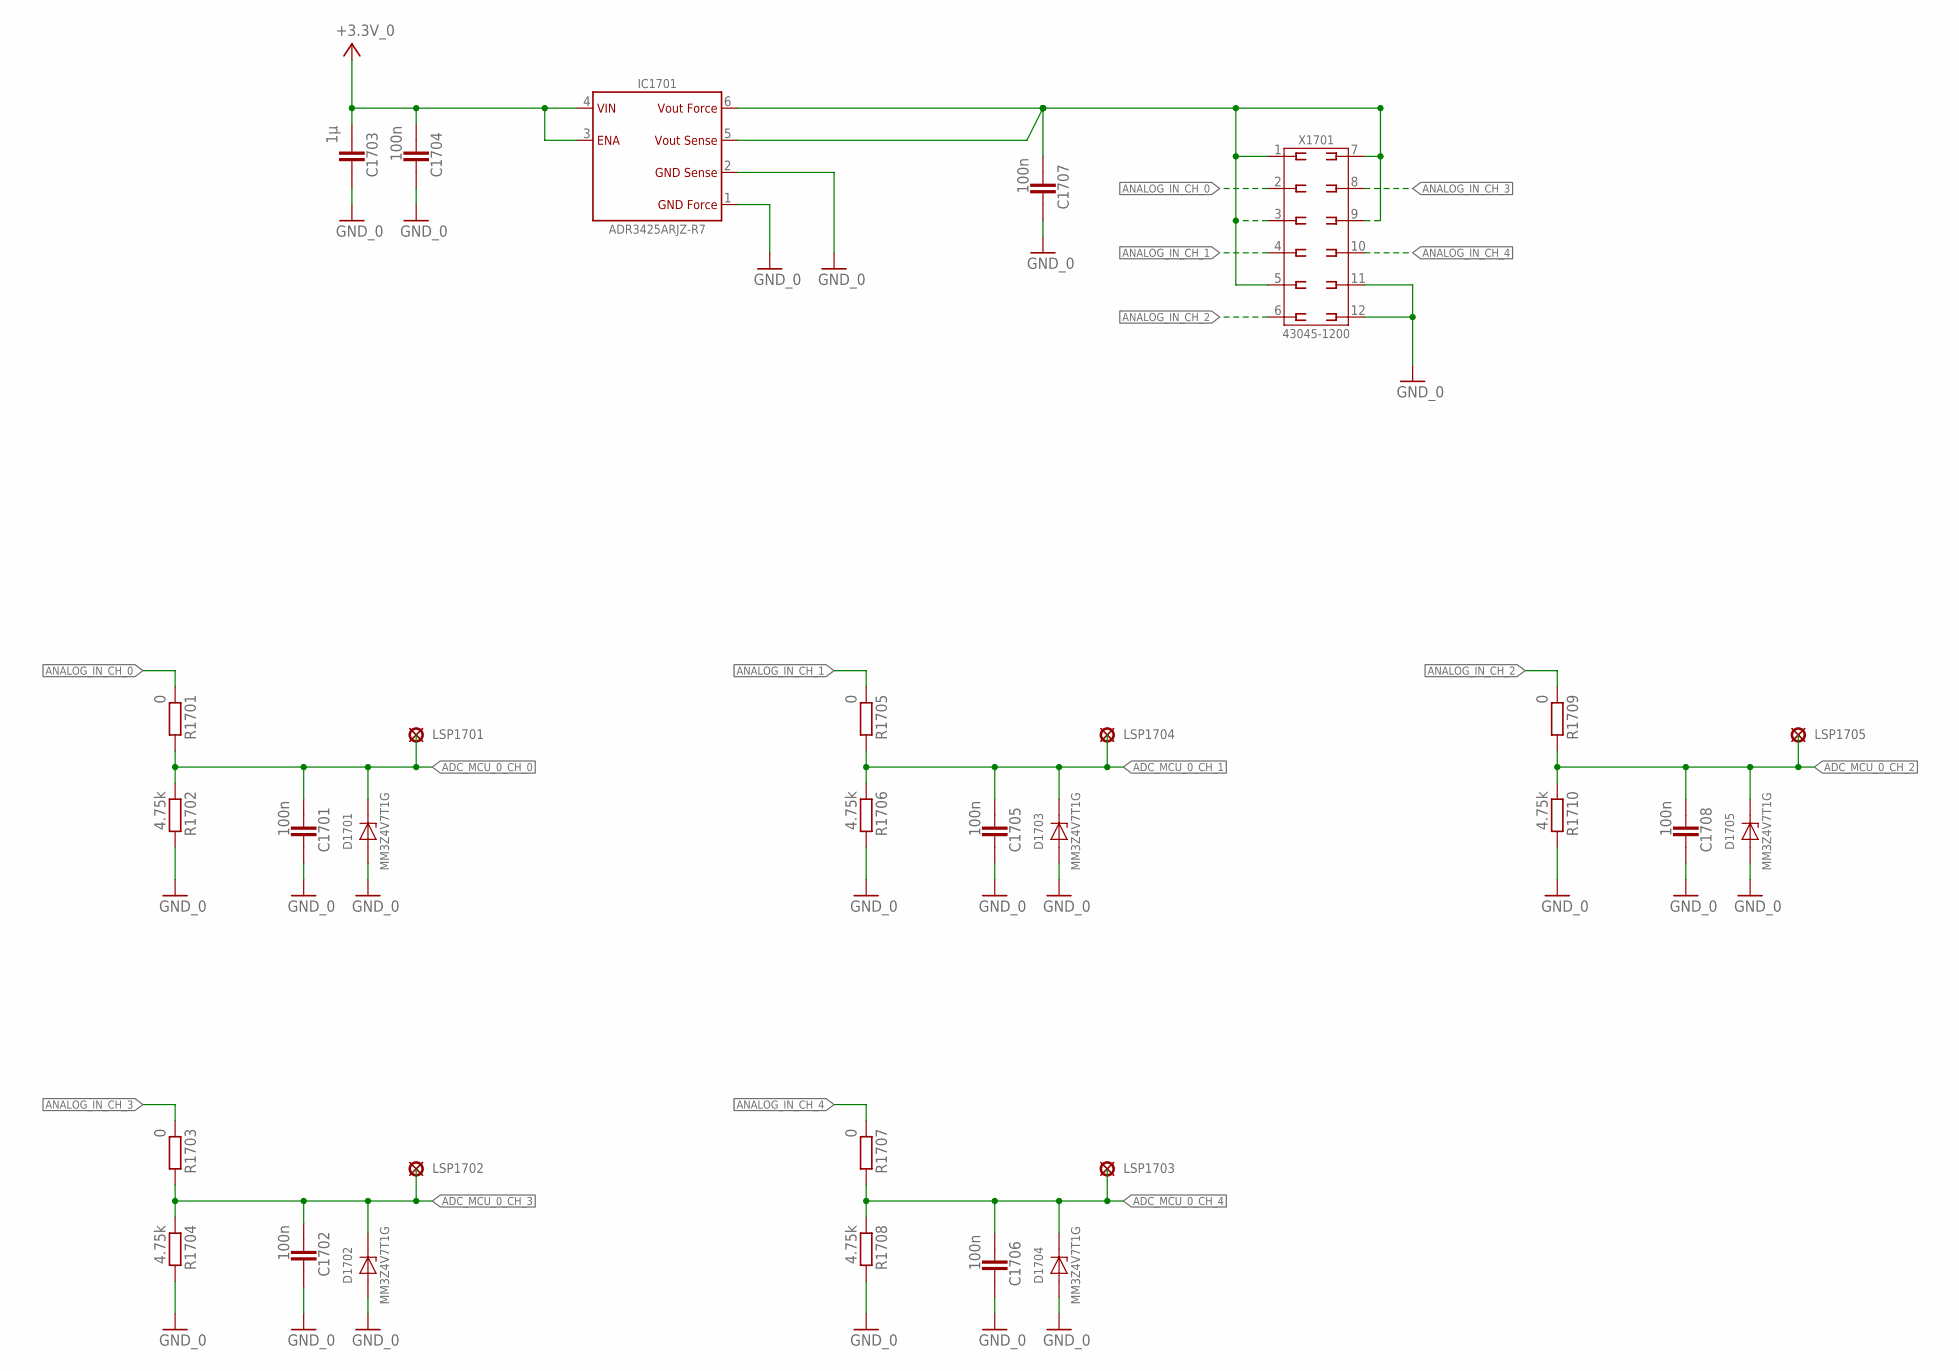
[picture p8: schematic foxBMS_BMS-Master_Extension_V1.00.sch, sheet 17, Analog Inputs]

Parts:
C1701, C1702, C1704, C1705, C1706, C1707, C1708: 100n; 0603
C1703: 1µ; 0603
D1701, D1702, D1703, D1704, D1705: MM3Z3V3ST1G; D_SMD_SOD323_(SC-76)_R_ON_REV01
IC1701: ADR3425ARJZ; IC_SMD_SOT23-6_(MO-178-AB)_R_AD_REV01
LSP1701, LSP1702, LSP1703, LSP1704, LSP1705: PAD_2.0X1.5MM; PAD2.0X1.5MM
R1701, R1703, R1705, R1707, R1709: 0; 0603
R1702, R1704, R1706, R1708, R1710: 4.75k; 0603
X1701: 43045-1200_MOLEX_12PIN; X_TH_MOLEX_43045-1200_R_REV01

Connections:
+3.3V_0: C1703.1, C1704.1, IC1701.3 (ENABLE), IC1701.4 (VIN); also elsewhere on the board
ADC_MCU_0_CH_0: C1701.1, D1701.C, LSP1701.P$1, R1701.2, R1702.1; also elsewhere on the board
ADC_MCU_0_CH_1: C1705.1, D1703.C, LSP1704.P$1, R1705.2, R1706.1; also elsewhere on the board
ADC_MCU_0_CH_2: C1708.1, D1705.C, LSP1705.P$1, R1709.2, R1710.1; also elsewhere on the board
ADC_MCU_0_CH_3: C1702.1, D1702.C, LSP1702.P$1, R1703.2, R1704.1; also elsewhere on the board
ADC_MCU_0_CH_4: C1706.1, D1704.C, LSP1703.P$1, R1707.2, R1708.1; also elsewhere on the board
ANALOG_IN_CH_0: R1701.1, X1701.2
ANALOG_IN_CH_1: R1705.1, X1701.4
ANALOG_IN_CH_2: R1709.1, X1701.6
ANALOG_IN_CH_3: R1703.1, X1701.8
ANALOG_IN_CH_4: R1707.1, X1701.10
GND_0: C1701.2, C1702.2, C1703.2, C1704.2, C1705.2, C1706.2, C1707.2, C1708.2, D1701.A, D1702.A, D1703.A, D1704.A, D1705.A, IC1701.1 (GND_FORCE), IC1701.2 (GND_SENSE), R1702.2, R1704.2, R1706.2, R1708.2, R1710.2, X1701.11, X1701.12; also elsewhere on the board
unnamed: C1707.1, IC1701.5 (VOUT_SENSE), IC1701.6 (VOUT_FORCE), X1701.1, X1701.3, X1701.5, X1701.7, X1701.9

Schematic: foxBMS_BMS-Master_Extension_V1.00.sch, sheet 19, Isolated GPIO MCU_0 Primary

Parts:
C1901, C1903, C1904, C1905, C1906, C1907: 100n; 0603
C1902: 1µ; 0603
D1901, D1902, D1903, D1904: CDSOD323-T05; D_SMD_SOD323_(SC-76)_R_BOURNS_REV01
IC1901: UA78L05ACPK; IC_SMD_SOT-89_(SC-62/TO-243)_(R-PSSO-F3)_R_TI_REV01
IC1902, IC1903: ADUM1402ARW; IC_SMD_SOIC-16_(JEDEC_MS-013-AA)_R_ANALOG_REV01
LSP1901, LSP1902, LSP1903, LSP1904, LSP1905, LSP1906, LSP1907, LSP1908: PAD_2.0X1.5MM; PAD2.0X1.5MM
R1901, R1902, R1905, R1906: 500; 0603
R1903, R1904, R1907, R1908: 10k; 0603
X1901: 43045-1000_MOLEX_10PIN; X_TH_MOLEX_43045-1000_R_REV01

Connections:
+3.3V_0: C1905.1, C1907.1, IC1902.10 (VE2), IC1902.16 (VDD2), IC1903.10 (VE2), IC1903.16 (VDD2); also elsewhere on the board
GND_0: C1905.2, C1907.2, IC1902.9 (GND2), IC1902.15 (GND2), IC1903.9 (GND2), IC1903.15 (GND2); also elsewhere on the board
GND_EXT_0: C1901.2, C1902.2, C1903.2, C1904.2, C1906.2, D1901.A, D1902.A, D1903.A, D1904.A, IC1901.2 (COM), IC1902.2 (GND1), IC1902.8 (GND1), IC1903.2 (GND1), IC1903.8 (GND1), R1903.1, R1904.1, R1907.1, R1908.1, X1901.9, X1901.10; also elsewhere on the board
ISO_GPIO_MCU_0_IN_0: IC1902.14 (VOA), LSP1903.P$1; also elsewhere on the board
ISO_GPIO_MCU_0_IN_0_EXT: R1904.2, X1901.5
ISO_GPIO_MCU_0_IN_1: IC1902.13 (VOB), LSP1901.P$1; also elsewhere on the board
ISO_GPIO_MCU_0_IN_1_EXT: IC1902.4 (VIB), R1903.2, X1901.6
ISO_GPIO_MCU_0_IN_2: IC1903.14 (VOA), LSP1905.P$1; also elsewhere on the board
ISO_GPIO_MCU_0_IN_2_EXT: IC1903.3 (VIA), R1908.2, X1901.7
ISO_GPIO_MCU_0_IN_3: IC1903.13 (VOB), LSP1907.P$1; also elsewhere on the board
ISO_GPIO_MCU_0_IN_3_EXT: IC1903.4 (VIB), R1907.2, X1901.8
ISO_GPIO_MCU_0_OUT_0: IC1902.12 (VIC), LSP1904.P$1; also elsewhere on the board
ISO_GPIO_MCU_0_OUT_0_EXT: R1901.2, X1901.1
ISO_GPIO_MCU_0_OUT_1: IC1902.11 (VID), LSP1902.P$1; also elsewhere on the board
ISO_GPIO_MCU_0_OUT_1_EXT: R1902.2, X1901.2
ISO_GPIO_MCU_0_OUT_2: IC1903.12 (VIC), LSP1906.P$1; also elsewhere on the board
ISO_GPIO_MCU_0_OUT_2_EXT: R1905.2, X1901.3
ISO_GPIO_MCU_0_OUT_3: IC1903.11 (VID), LSP1908.P$1; also elsewhere on the board
ISO_GPIO_MCU_0_OUT_3_EXT: R1906.2, X1901.4
ISO_GPIO_SUPPLY: C1903.1, C1904.1, C1906.1, IC1901.1 (OUT), IC1902.1 (VDD1), IC1902.7 (VE1), IC1903.1 (VDD1), IC1903.7 (VE1)
unnamed: D1901.C, IC1902.5 (VOC), R1901.1
unnamed: D1902.C, IC1902.6 (VOD), R1902.1
unnamed: D1903.C, IC1903.5 (VOC), R1905.1
unnamed: D1904.C, IC1903.6 (VOD), R1906.1
SUPPLY_EXT_0: C1901.1, C1902.1, IC1901.3 (IN); also elsewhere on the board

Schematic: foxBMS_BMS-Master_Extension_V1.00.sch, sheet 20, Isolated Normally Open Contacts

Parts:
D2001, D2002, D2003, D2004, D2005, D2006: DIODE-DO214BA; DO214BA
IC2001, IC2002, IC2003, IC2004, IC2005, IC2006: AQV25G2S; SOP06
LSP2001, LSP2002, LSP2003, LSP2004, LSP2005, LSP2006: PAD_2.0X1.5MM; PAD2.0X1.5MM
R2001, R2002, R2007, R2008, R2013, R2014: 10; 0603
R2003, R2004, R2009, R2010, R2015, R2016: 10k; 0603
R2005, R2006, R2011, R2012, R2017, R2018: 430; 0603
T2001, T2002, T2003, T2004, T2005, T2006: IRLML0100TRPBF; V_SMD_SOT-23_(TO-236AB)_R_IR_REV01
X2001: 43045-1200_MOLEX_12PIN; X_TH_MOLEX_43045-1200_R_REV01

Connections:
+3.3V_0: IC2001.1 (A), IC2002.1 (A), IC2003.1 (A), IC2004.1 (A), IC2005.1 (A), IC2006.1 (A); also elsewhere on the board
GND_0: R2003.1, R2004.1, R2009.1, R2010.1, R2015.1, R2016.1, T2001.2 (S), T2002.2 (S), T2003.2 (S), T2004.2 (S), T2005.2 (S), T2006.2 (S); also elsewhere on the board
ISONOC_0_CONTROL: LSP2001.P$1, R2001.2; also elsewhere on the board
ISONOC_0_NEGATIVE: D2001.A, IC2001.5 (S), X2001.7
ISONOC_0_POSITIVE: D2001.C, IC2001.4 (D1), IC2001.6 (D2), X2001.1
ISONOC_1_CONTROL: LSP2003.P$1, R2007.2; also elsewhere on the board
ISONOC_1_NEGATIVE: D2003.A, IC2003.5 (S), X2001.8
ISONOC_1_POSITIVE: D2003.C, IC2003.4 (D1), IC2003.6 (D2), X2001.2
ISONOC_2_CONTROL: LSP2005.P$1, R2013.2; also elsewhere on the board
ISONOC_2_NEGATIVE: D2005.A, IC2005.5 (S), X2001.9
ISONOC_2_POSITIVE: D2005.C, IC2005.4 (D1), IC2005.6 (D2), X2001.3
ISONOC_3_CONTROL: LSP2002.P$1, R2002.2; also elsewhere on the board
ISONOC_3_NEGATIVE: D2002.A, IC2002.5 (S), X2001.10
ISONOC_3_POSITIVE: D2002.C, IC2002.4 (D1), IC2002.6 (D2), X2001.4
ISONOC_4_CONTROL: LSP2004.P$1, R2008.2; also elsewhere on the board
ISONOC_4_NEGATIVE: D2004.A, IC2004.5 (S), X2001.11
ISONOC_4_POSITIVE: D2004.C, IC2004.4 (D1), IC2004.6 (D2), X2001.5
ISONOC_5_CONTROL: LSP2006.P$1, R2014.2; also elsewhere on the board
ISONOC_5_NEGATIVE: D2006.A, IC2006.5 (S), X2001.12
ISONOC_5_POSITIVE: D2006.C, IC2006.4 (D1), IC2006.6 (D2), X2001.6
unnamed: R2005.1, T2001.3 (D)
unnamed: R2011.1, T2003.3 (D)
unnamed: IC2003.2 (K), R2011.2
unnamed: R2017.1, T2005.3 (D)
unnamed: IC2005.2 (K), R2017.2
unnamed: R2006.1, T2002.3 (D)
unnamed: IC2002.2 (K), R2006.2
unnamed: R2012.1, T2004.3 (D)
unnamed: IC2004.2 (K), R2012.2
unnamed: R2018.1, T2006.3 (D)
unnamed: IC2006.2 (K), R2018.2
unnamed: IC2001.2 (K), R2005.2
unnamed: R2001.1, R2003.2, T2001.1 (G)
unnamed: R2007.1, R2009.2, T2003.1 (G)
unnamed: R2013.1, R2015.2, T2005.1 (G)
unnamed: R2002.1, R2004.2, T2002.1 (G)
unnamed: R2008.1, R2010.2, T2004.1 (G)
unnamed: R2014.1, R2016.2, T2006.1 (G)

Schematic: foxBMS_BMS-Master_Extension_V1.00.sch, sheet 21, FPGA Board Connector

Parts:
LSP2101, LSP2102: PAD_2.0X1.5MM; PAD2.0X1.5MM
SV2101: MA04-2

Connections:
+3.3V_0: LSP2101.P$1, SV2101.1; also elsewhere on the board
+5.0V_0: SV2101.2
GND_0: LSP2102.P$1, SV2101.5, SV2101.6; also elsewhere on the board
MCU_TO_FPGA_INTERFACE_MCU_0_CS: SV2101.8
MCU_TO_FPGA_INTERFACE_MCU_0_MISO: SV2101.3
MCU_TO_FPGA_INTERFACE_MCU_0_MOSI: SV2101.7
MCU_TO_FPGA_INTERFACE_MCU_0_SCK: SV2101.4

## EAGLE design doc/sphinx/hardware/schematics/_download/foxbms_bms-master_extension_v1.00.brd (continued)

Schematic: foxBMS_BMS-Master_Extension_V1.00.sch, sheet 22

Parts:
JP2201, JP2202: PINHD-2X12; 2X12

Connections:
+3.3V_0: JP2201.1, JP2201.3, JP2202.1, JP2202.3; also elsewhere on the board
ADC_MCU_0_CH_0: JP2202.8; also elsewhere on the board
ADC_MCU_0_CH_1: JP2202.7; also elsewhere on the board
ADC_MCU_0_CH_2: JP2202.6; also elsewhere on the board
ADC_MCU_0_CH_3: JP2202.5; also elsewhere on the board
ADC_MCU_0_CH_4: JP2202.9; also elsewhere on the board
CAN_1_RX: JP2201.6; also elsewhere on the board
CAN_1_TRANS_STANDBY_CONTROL: JP2201.5; also elsewhere on the board
CAN_1_TX: JP2201.7; also elsewhere on the board
CONTACTOR_6_CONTROL: JP2201.18; also elsewhere on the board
CONTACTOR_6_FEEDBACK: JP2201.17; also elsewhere on the board
CONTACTOR_7_CONTROL: JP2201.16; also elsewhere on the board
CONTACTOR_7_FEEDBACK: JP2201.15; also elsewhere on the board
CONTACTOR_8_CONTROL: JP2202.10; also elsewhere on the board
CONTACTOR_8_FEEDBACK: JP2202.11; also elsewhere on the board
DATA_STORAGE_SPI_MISO: JP2201.21; also elsewhere on the board
DATA_STORAGE_SPI_MOSI: JP2201.19; also elsewhere on the board
DATA_STORAGE_SPI_SCK: JP2201.20; also elsewhere on the board
DATA_STORAGE_SPI_SDCARD_NSS: JP2201.23; also elsewhere on the board
GND_0: JP2201.2, JP2201.4, JP2202.2, JP2202.4; also elsewhere on the board
ISONOC_0_CONTROL: JP2202.16; also elsewhere on the board
ISONOC_1_CONTROL: JP2202.17; also elsewhere on the board
ISONOC_2_CONTROL: JP2202.18; also elsewhere on the board
ISONOC_3_CONTROL: JP2202.19; also elsewhere on the board
ISONOC_4_CONTROL: JP2202.20; also elsewhere on the board
ISONOC_5_CONTROL: JP2202.21; also elsewhere on the board
ISO_GPIO_MCU_0_IN_0: JP2202.22; also elsewhere on the board
ISO_GPIO_MCU_0_IN_1: JP2202.23; also elsewhere on the board
ISO_GPIO_MCU_0_IN_2: JP2201.13; also elsewhere on the board
ISO_GPIO_MCU_0_IN_3: JP2201.10; also elsewhere on the board
ISO_GPIO_MCU_0_OUT_0: JP2201.9; also elsewhere on the board
ISO_GPIO_MCU_0_OUT_1: JP2201.14; also elsewhere on the board
ISO_GPIO_MCU_0_OUT_2: JP2201.11; also elsewhere on the board
ISO_GPIO_MCU_0_OUT_3: JP2201.12; also elsewhere on the board
RS485_MCU_0_DE: JP2202.15; also elsewhere on the board
RS485_MCU_0_NRE: JP2202.14; also elsewhere on the board
RS485_MCU_0_RX: JP2202.13; also elsewhere on the board
RS485_MCU_0_TX: JP2202.12; also elsewhere on the board
SDCARD_SUPPLY_CONTROL: JP2201.22; also elsewhere on the board

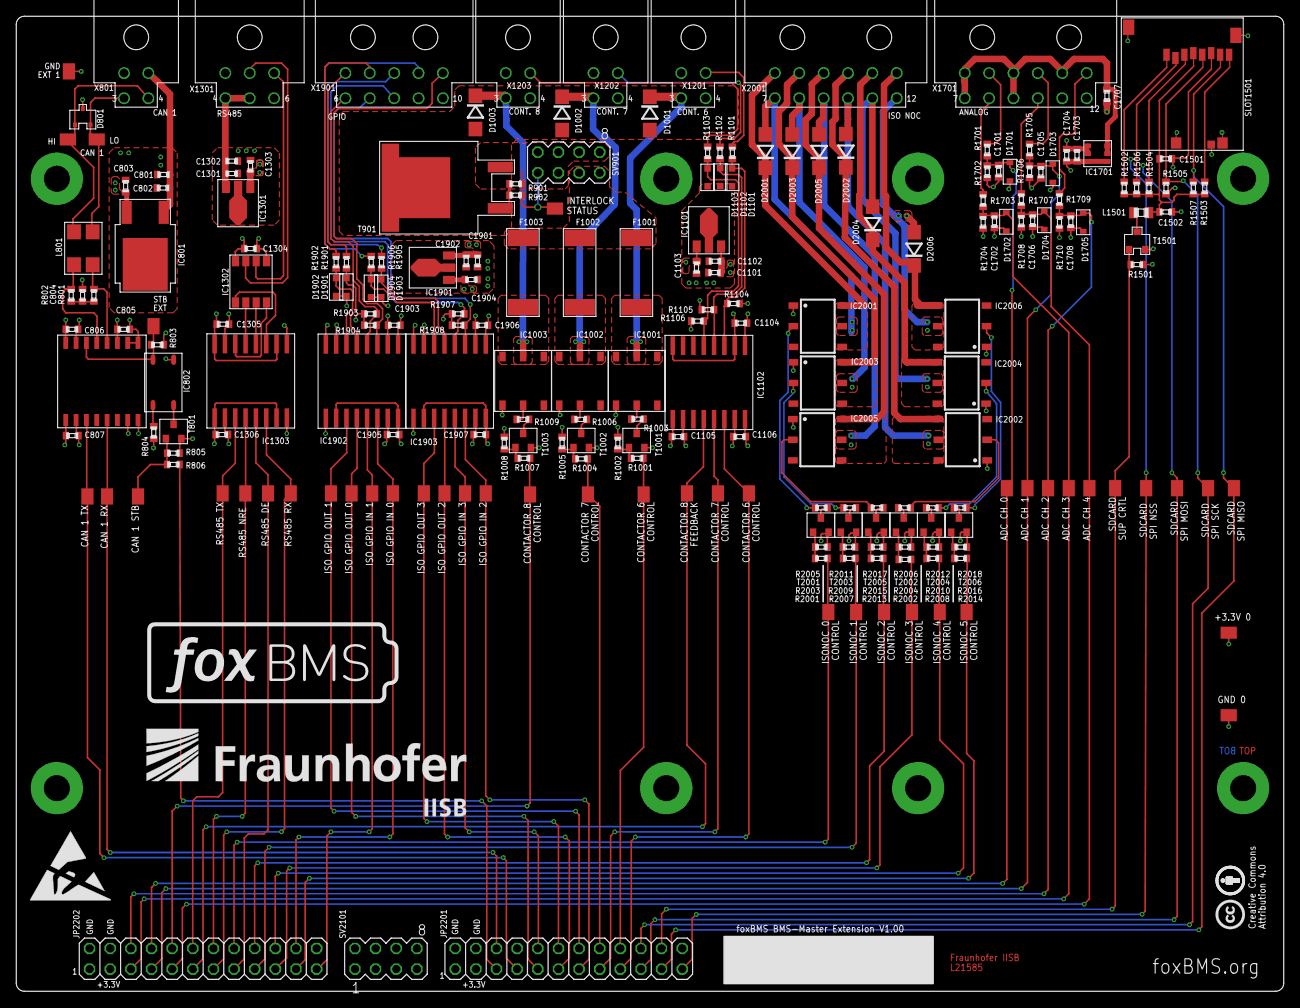
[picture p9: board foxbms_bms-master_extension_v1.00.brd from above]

Board: 4 copper layers, 156.0 x 120.0 mm, 220 parts (0 on the bottom side), 141 nets.

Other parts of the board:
U$1: ESD_10.00

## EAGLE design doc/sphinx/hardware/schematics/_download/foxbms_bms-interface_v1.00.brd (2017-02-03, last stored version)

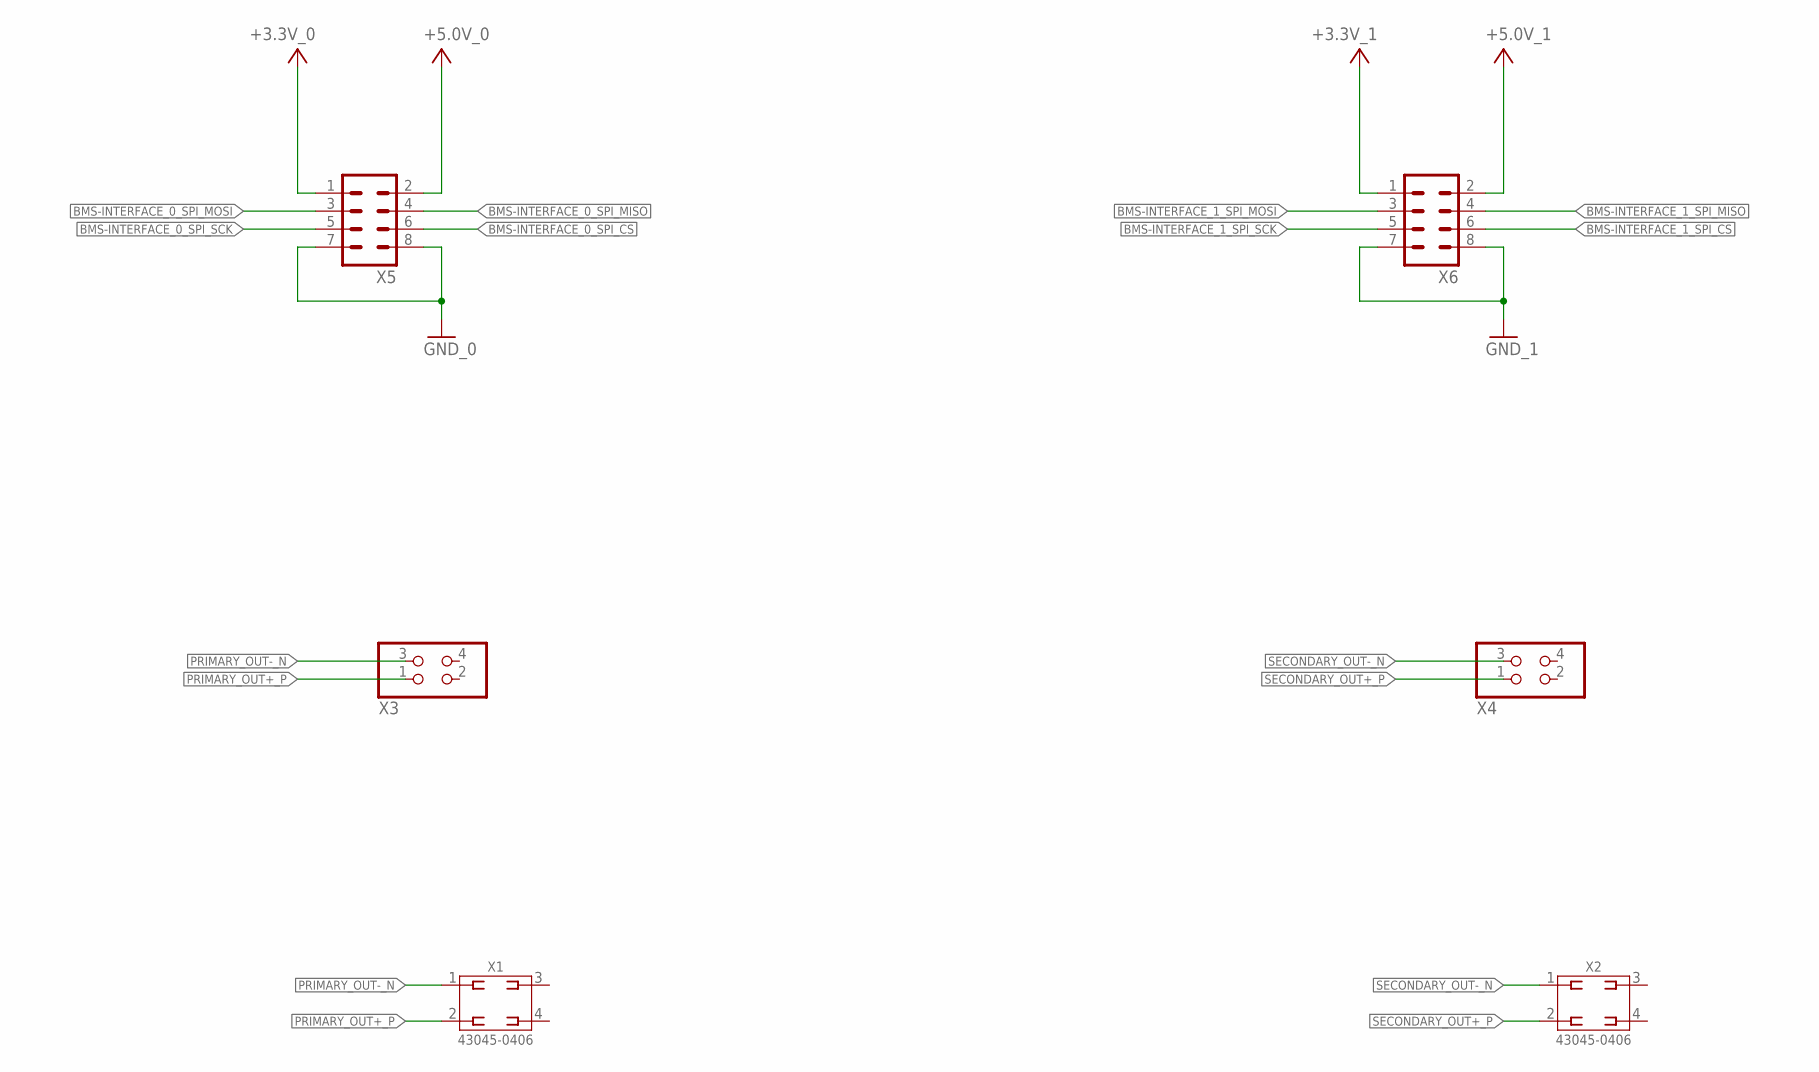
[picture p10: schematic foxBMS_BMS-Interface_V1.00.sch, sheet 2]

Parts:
X1, X2: 43045-0406_MOLEX_4PIN; X_SMD_MOLEX_43045-0408_R_REV01
X3, X4: PINHD-2X2; 2X02
X5, X6: MA04-2

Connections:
+3.3V_0: X5.1; also elsewhere on the board
+3.3V_1: X6.1; also elsewhere on the board
+5.0V_0: X5.2
+5.0V_1: X6.2
BMS-INTERFACE_0_SPI_CS: X5.6; also elsewhere on the board
BMS-INTERFACE_0_SPI_MISO: X5.4; also elsewhere on the board
BMS-INTERFACE_0_SPI_MOSI: X5.3; also elsewhere on the board
BMS-INTERFACE_0_SPI_SCK: X5.5; also elsewhere on the board
BMS-INTERFACE_1_SPI_CS: X6.6; also elsewhere on the board
BMS-INTERFACE_1_SPI_MISO: X6.4; also elsewhere on the board
BMS-INTERFACE_1_SPI_MOSI: X6.3; also elsewhere on the board
BMS-INTERFACE_1_SPI_SCK: X6.5; also elsewhere on the board
GND_0: X5.7, X5.8; also elsewhere on the board
GND_1: X6.7, X6.8; also elsewhere on the board
PRIMARY_OUT+_P: X1.2, X3.1; also elsewhere on the board
PRIMARY_OUT-_N: X1.1, X3.3; also elsewhere on the board
SECONDARY_OUT+_P: X2.2, X4.1; also elsewhere on the board
SECONDARY_OUT-_N: X2.1, X4.3; also elsewhere on the board

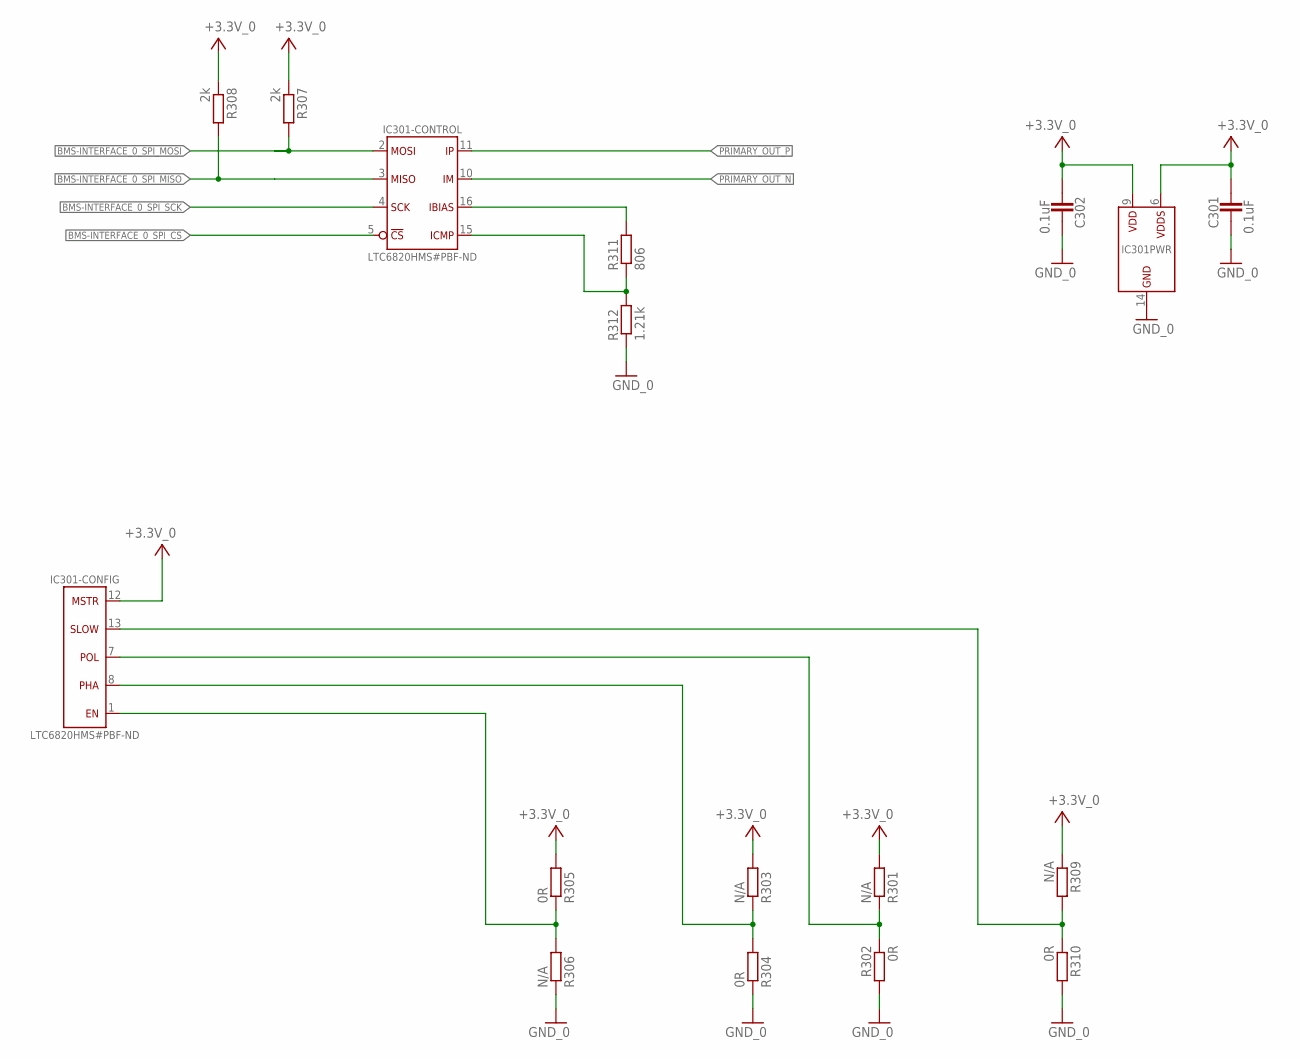
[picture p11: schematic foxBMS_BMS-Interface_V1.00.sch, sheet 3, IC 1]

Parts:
C301, C302: 0.1uF; 0603
IC301: LTC6820HMS#PBF; IC_SMD_MSOP-16_(MS16)_R_LINEAR_REV01
R301, R303, R306, R309: N/A; 0603
R302, R304, R305, R310: 0R; 0603
R307, R308: 2k; 0603
R311: 806; 0603
R312: 1.21k; 0603

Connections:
+3.3V_0: C301.2, C302.2, IC301.6 (VDDS), IC301.9 (VDD), IC301.12 (MSTR), R301.2, R303.2, R305.2, R307.1, R308.1, R309.1; also elsewhere on the board
BMS-INTERFACE_0_SPI_CS: IC301.5 (!CS); also elsewhere on the board
BMS-INTERFACE_0_SPI_MISO: IC301.3 (MISO), R308.2; also elsewhere on the board
BMS-INTERFACE_0_SPI_MOSI: IC301.2 (MOSI), R307.2; also elsewhere on the board
BMS-INTERFACE_0_SPI_SCK: IC301.4 (SCK); also elsewhere on the board
EN-BACKUP: IC301.1 (EN), R305.1, R306.2
GND_0: C301.1, C302.1, IC301.14 (GND), R302.2, R304.1, R306.1, R310.2, R312.1; also elsewhere on the board
unnamed: IC301.16 (IBIAS), R311.2
unnamed: IC301.15 (ICMP), R311.1, R312.2
PHA-PRIMARY: IC301.8 (PHA), R303.1, R304.2
POL-PRIMARY: IC301.7 (POL), R301.1, R302.1
PRIMARY_OUT_N: IC301.10 (IM); also elsewhere on the board
PRIMARY_OUT_P: IC301.11 (IP); also elsewhere on the board
SLOW-PRIMARY: IC301.13 (SLOW), R309.2, R310.1

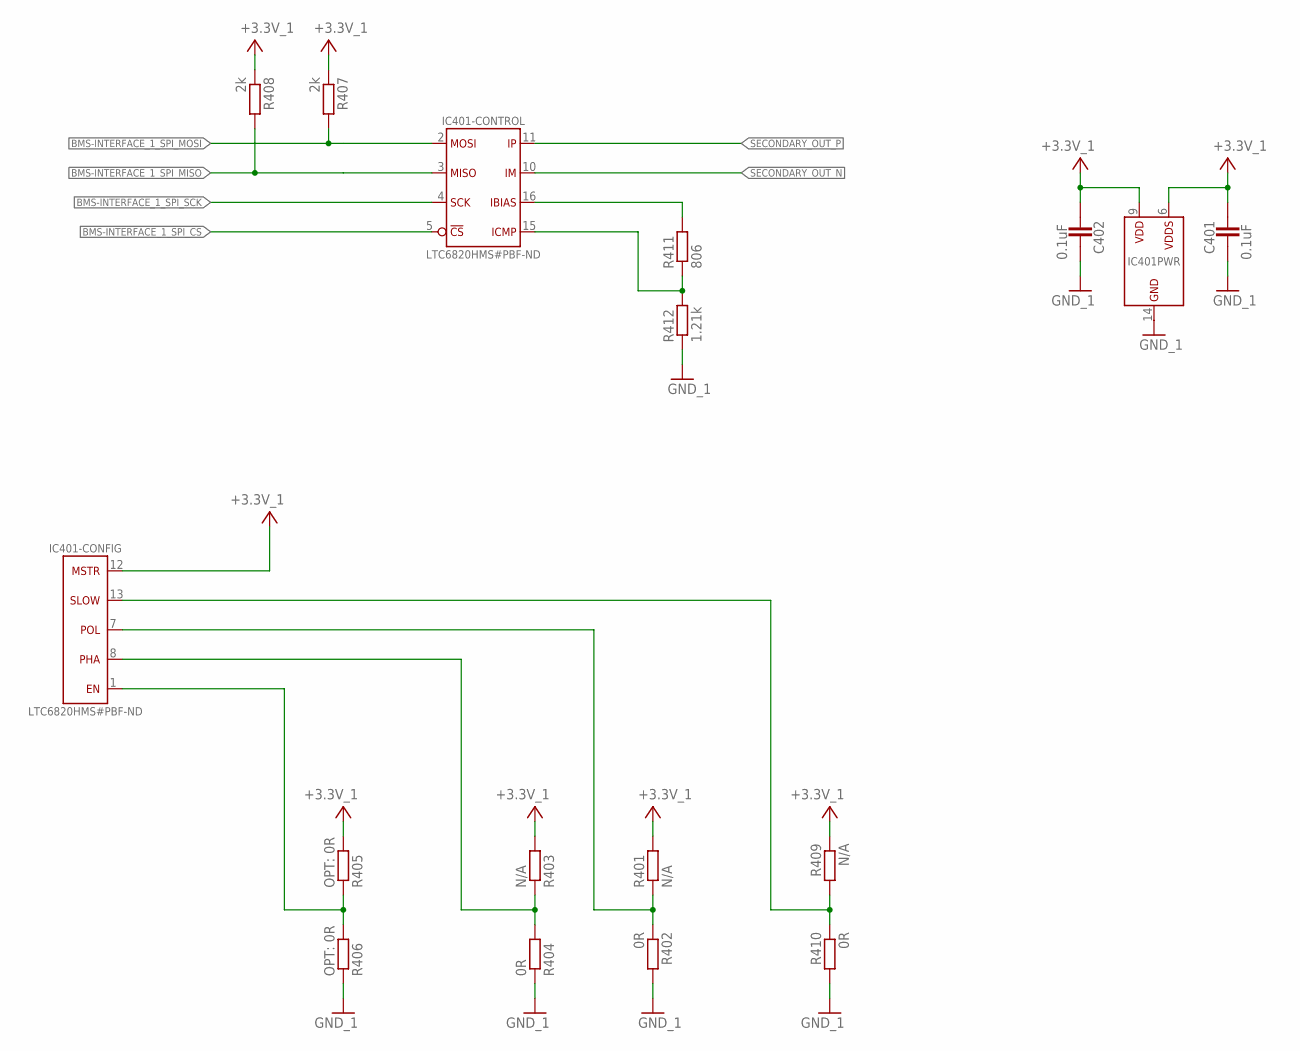
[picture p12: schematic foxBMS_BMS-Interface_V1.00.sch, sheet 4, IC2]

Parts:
C401, C402: 0.1uF; 0603
IC401: LTC6820HMS#PBF; IC_SMD_MSOP-16_(MS16)_R_LINEAR_REV01
R401, R403, R409: N/A; 0603
R402, R404, R410: 0R; 0603
R405, R406: OPT: 0R; 0603
R407, R408: 2k; 0603
R411: 806; 0603
R412: 1.21k; 0603

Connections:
+3.3V_1: C401.2, C402.2, IC401.6 (VDDS), IC401.9 (VDD), IC401.12 (MSTR), R401.2, R403.2, R405.2, R407.1, R408.1, R409.1; also elsewhere on the board
BMS-INTERFACE_1_SPI_CS: IC401.5 (!CS); also elsewhere on the board
BMS-INTERFACE_1_SPI_MISO: IC401.3 (MISO), R408.2; also elsewhere on the board
BMS-INTERFACE_1_SPI_MOSI: IC401.2 (MOSI), R407.2; also elsewhere on the board
BMS-INTERFACE_1_SPI_SCK: IC401.4 (SCK); also elsewhere on the board
EN-BACKUP1: IC401.1 (EN), R405.1, R406.2
GND_1: C401.1, C402.1, IC401.14 (GND), R402.2, R404.1, R406.1, R410.2, R412.1; also elsewhere on the board
unnamed: IC401.15 (ICMP), R411.1, R412.2
unnamed: IC401.16 (IBIAS), R411.2
PHA-SECONDARY: IC401.8 (PHA), R403.1, R404.2
POL-SECONDARY: IC401.7 (POL), R401.1, R402.1
SECONDARY_OUT_N: IC401.10 (IM); also elsewhere on the board
SECONDARY_OUT_P: IC401.11 (IP); also elsewhere on the board
SLOW-SECONDARY: IC401.13 (SLOW), R409.2, R410.1


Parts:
C501, C503: 1uF; 0603
C502, C504: 27pF; 0603
R501, R502: 120; 0603
T501, T502: HX1188NL; TR_SMD_SOIC-16_(12,70MMX9,53MMX5,97MM)_R_PULSE_REV01

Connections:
GND_0: C502.1; also elsewhere on the board
GND_1: C504.1; also elsewhere on the board
GND_EXT_0: C501.1
GND_EXT_1: C503.1
unnamed: C504.2, T502.2 (CT)
unnamed: C503.2, T502.15 (CMT)
unnamed: C502.2, T501.7 (CT)
unnamed: C501.2, T501.10 (CMT)
PRIMARY_OUT+_P: T501.11 (X+); also elsewhere on the board
PRIMARY_OUT-_N: T501.9 (X-); also elsewhere on the board
PRIMARY_OUT_N: R501.1, T501.8 (D-); also elsewhere on the board
PRIMARY_OUT_P: R501.2, T501.6 (D+); also elsewhere on the board
SECONDARY_OUT+_P: T502.16 (X+); also elsewhere on the board
SECONDARY_OUT-_N: T502.14 (X-); also elsewhere on the board
SECONDARY_OUT_N: R502.1, T502.3 (D-); also elsewhere on the board
SECONDARY_OUT_P: R502.2, T502.1 (D+); also elsewhere on the board



Board: 4 copper layers, 50.0 x 100.0 mm, 44 parts (4 on the bottom side), 36 nets.

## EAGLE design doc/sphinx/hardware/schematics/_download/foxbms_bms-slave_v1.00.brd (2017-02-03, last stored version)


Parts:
IC201: LTC6804HG-1#PBF; IC_SMD_SSOP-48_(G48)_R_LINEAR_REV01

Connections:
+3.0V_VREF2_0: IC201.34 (VREF2); also elsewhere on the board
+5.0V_VREG_0: IC201.37 (VREG); also elsewhere on the board
FUSED_VBAT-: IC201.30 (V-1), IC201.31 (V-2); also elsewhere on the board
PRIMARY-C0: IC201.26 (C0); also elsewhere on the board
PRIMARY-C1: IC201.24 (C1); also elsewhere on the board
PRIMARY-C2: IC201.22 (C2); also elsewhere on the board
PRIMARY-C3: IC201.20 (C3); also elsewhere on the board
PRIMARY-C4: IC201.18 (C4); also elsewhere on the board
PRIMARY-C5: IC201.16 (C5); also elsewhere on the board
PRIMARY-C6: IC201.14 (C6); also elsewhere on the board
PRIMARY-C7: IC201.12 (C7); also elsewhere on the board
PRIMARY-C8: IC201.10 (C8); also elsewhere on the board
PRIMARY-C9: IC201.8 (C9); also elsewhere on the board
PRIMARY-C10: IC201.6 (C10); also elsewhere on the board
PRIMARY-C11: IC201.4 (C11); also elsewhere on the board
PRIMARY-C12: IC201.2 (C12); also elsewhere on the board
PRIMARY-DRIVE: IC201.38 (DRIVE); also elsewhere on the board
PRIMARY-GPIO0: IC201.27 (GPIO1); also elsewhere on the board
PRIMARY-GPIO1: IC201.28 (GPIO2); also elsewhere on the board
PRIMARY-GPIO2: IC201.29 (GPIO3); also elsewhere on the board
PRIMARY-GPIO3: IC201.32 (GPIO4); also elsewhere on the board
PRIMARY-GPIO4: IC201.33 (GPIO5); also elsewhere on the board
PRIMARY-IBIAS: IC201.45 (IBIAS); also elsewhere on the board
PRIMARY-ICMP: IC201.46 (ICMP); also elsewhere on the board
PRIMARY-IN_N: IC201.41 (CSB/IMA); also elsewhere on the board
PRIMARY-IN_P: IC201.42 (SCK/IPA); also elsewhere on the board
PRIMARY-ISOMD: IC201.40 (ISOMD); also elsewhere on the board
PRIMARY-OUT_N: IC201.47 (IMB); also elsewhere on the board
PRIMARY-OUT_P: IC201.48 (IPB); also elsewhere on the board
PRIMARY-SWTEN: IC201.36 (SWTEN); also elsewhere on the board
PRIMARY-V+: IC201.1 (V+); also elsewhere on the board
PRIMARY-VREF1: IC201.35 (VREF1); also elsewhere on the board
PRIMARY-WDT: IC201.39 (WDT); also elsewhere on the board
S0: IC201.25 (S1); also elsewhere on the board
S1: IC201.23 (S2); also elsewhere on the board
S2: IC201.21 (S3); also elsewhere on the board
S3: IC201.19 (S4); also elsewhere on the board
S4: IC201.17 (S5); also elsewhere on the board
S5: IC201.15 (S6); also elsewhere on the board
S6: IC201.13 (S7); also elsewhere on the board
S7: IC201.11 (S8); also elsewhere on the board
S8: IC201.9 (S9); also elsewhere on the board
S9: IC201.7 (S10); also elsewhere on the board
S10: IC201.5 (S11); also elsewhere on the board
S11: IC201.3 (S12); also elsewhere on the board


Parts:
IC301: LTC6804HG-1#PBF; IC_SMD_SSOP-48_(G48)_R_LINEAR_REV01

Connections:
+3.0V_VREF2_1: IC301.34 (VREF2); also elsewhere on the board
+5.0V_VREG_1: IC301.37 (VREG); also elsewhere on the board
FUSED_VBAT-: IC301.30 (V-1), IC301.31 (V-2); also elsewhere on the board
SECONDARY-C0: IC301.26 (C0); also elsewhere on the board
SECONDARY-C1: IC301.24 (C1); also elsewhere on the board
SECONDARY-C2: IC301.22 (C2); also elsewhere on the board
SECONDARY-C3: IC301.20 (C3); also elsewhere on the board
SECONDARY-C4: IC301.18 (C4); also elsewhere on the board
SECONDARY-C5: IC301.16 (C5); also elsewhere on the board
SECONDARY-C6: IC301.14 (C6); also elsewhere on the board
SECONDARY-C7: IC301.12 (C7); also elsewhere on the board
SECONDARY-C8: IC301.10 (C8); also elsewhere on the board
SECONDARY-C9: IC301.8 (C9); also elsewhere on the board
SECONDARY-C10: IC301.6 (C10); also elsewhere on the board
SECONDARY-C11: IC301.4 (C11); also elsewhere on the board
SECONDARY-C12: IC301.2 (C12); also elsewhere on the board
SECONDARY-DRIVE: IC301.38 (DRIVE); also elsewhere on the board
SECONDARY-GPIO0: IC301.27 (GPIO1); also elsewhere on the board
SECONDARY-GPIO1: IC301.28 (GPIO2); also elsewhere on the board
SECONDARY-GPIO2: IC301.29 (GPIO3); also elsewhere on the board
SECONDARY-GPIO3: IC301.32 (GPIO4); also elsewhere on the board
SECONDARY-GPIO4: IC301.33 (GPIO5); also elsewhere on the board
SECONDARY-IBIAS: IC301.45 (IBIAS); also elsewhere on the board
SECONDARY-ICMP: IC301.46 (ICMP); also elsewhere on the board
SECONDARY-IN_N: IC301.41 (CSB/IMA); also elsewhere on the board
SECONDARY-IN_P: IC301.42 (SCK/IPA); also elsewhere on the board
SECONDARY-ISOMD: IC301.40 (ISOMD); also elsewhere on the board
SECONDARY-OUT_N: IC301.47 (IMB); also elsewhere on the board
SECONDARY-OUT_P: IC301.48 (IPB); also elsewhere on the board
SECONDARY-SWTEN: IC301.36 (SWTEN); also elsewhere on the board
SECONDARY-V+: IC301.1 (V+); also elsewhere on the board
SECONDARY-VREF1: IC301.35 (VREF1); also elsewhere on the board
SECONDARY-WDT: IC301.39 (WDT); also elsewhere on the board


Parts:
C401, C403, C405: 1uF, 20%, 16V; 0603
C402, C404, C406: 100nF, 10%, 100V; 0805
LSP401, LSP402, LSP403: PAD_2.0X1.5MM; PAD2.0X1.5MM
R401, R402: 100R, 1%, 1/10W; 0603
T401: PBHV8115Z; D_SMD_SOT223_(SC-73)_R_NXP_REV01
Z401: 60V,500mW; D_SMD_SOD-123_R_ON_REV01

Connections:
+3.0V_VREF2_0: C401.2, LSP403.P$1; also elsewhere on the board
+5.0V_VREG_0: C405.2, LSP401.P$1, T401.3 (E); also elsewhere on the board
FUSED_VBAT+: R401.2, R402.1; also elsewhere on the board
FUSED_VBAT-: C401.1, C402.2, C403.1, C404.2, C405.1, C406.1, Z401.A; also elsewhere on the board
unnamed: C406.2, R401.1, T401.2 (C), T401.4 (C)
PRIMARY-DRIVE: T401.1 (B); also elsewhere on the board
PRIMARY-V+: C402.1, C404.1, R402.2, Z401.K (C); also elsewhere on the board
PRIMARY-VREF1: C403.2, LSP402.P$1; also elsewhere on the board

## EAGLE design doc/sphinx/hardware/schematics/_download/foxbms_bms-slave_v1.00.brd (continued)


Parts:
C501, C503, C505: 1uF, 20%, 16V; 0603
C502, C504, C506: 100nF, 10%, 100V; 0805
LSP501, LSP502, LSP503: PAD_2.0X1.5MM; PAD2.0X1.5MM
R501, R502: 100R, 1%, 1/10W; 0603
T501: PBHV8115Z; D_SMD_SOT223_(SC-73)_R_NXP_REV01
Z501: 60V,500mW; D_SMD_SOD-123_R_ON_REV01

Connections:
+3.0V_VREF2_1: C501.2, LSP503.P$1; also elsewhere on the board
+5.0V_VREG_1: C505.2, LSP501.P$1, T501.3 (E); also elsewhere on the board
FUSED_VBAT+: R501.2, R502.1; also elsewhere on the board
FUSED_VBAT-: C501.1, C502.2, C503.1, C504.2, C505.1, C506.1, Z501.A; also elsewhere on the board
unnamed: C506.2, R501.1, T501.2 (C), T501.4 (C)
SECONDARY-DRIVE: T501.1 (B); also elsewhere on the board
SECONDARY-V+: C502.1, C504.1, R502.2, Z501.K (C); also elsewhere on the board
SECONDARY-VREF1: C503.2, LSP502.P$1; also elsewhere on the board


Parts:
C601, C602: 100pF, 15%, 25V; 0603
C603, C604: 1uF, 20%, 25V; 0603
LSP601, LSP602, LSP603, LSP604: PAD_2.0X1.5MM; PAD2.0X1.5MM
R601, R607: 0R; 0603
R602: 806, 1%, 1/10W; 0603
R603: 1.21k, 1%, 1/10W; 0603
R604, R605: 120R, 1%, 1/10W; 0603
R606: OPT: 0R; 0603
R608: 1M, 10%, 1/10W; 0603
TR601: HX1188NL; TR_SMD_SOIC-16_(12,70MMX9,53MMX5,97MM)_R_PULSE_REV01

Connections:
+5.0V_VREG_0: R601.2, R606.2, R608.2; also elsewhere on the board
FUSED_VBAT-: C601.1, C602.1, R603.2, R607.1; also elsewhere on the board
GND_1: C603.1, C604.1; also elsewhere on the board
unnamed: C601.2, TR601.2 (CT)
unnamed: C602.2, TR601.7 (CT)
unnamed: C604.2, TR601.15 (CMT)
unnamed: C603.2, TR601.10 (CMT)
PRIMARY-IBIAS: R602.1; also elsewhere on the board
PRIMARY-ICMP: R602.2, R603.1; also elsewhere on the board
PRIMARY-IN+_P: LSP601.P$1, TR601.16 (X+); also elsewhere on the board
PRIMARY-IN-_N: LSP602.P$1, TR601.14 (X-); also elsewhere on the board
PRIMARY-IN_N: R604.2, TR601.3 (D-); also elsewhere on the board
PRIMARY-IN_P: R604.1, TR601.1 (D+); also elsewhere on the board
PRIMARY-ISOMD: R601.1; also elsewhere on the board
PRIMARY-OUT+_P: LSP603.P$1, TR601.11 (X+); also elsewhere on the board
PRIMARY-OUT-_N: LSP604.P$1, TR601.9 (X-); also elsewhere on the board
PRIMARY-OUT_N: R605.2, TR601.8 (D-); also elsewhere on the board
PRIMARY-OUT_P: R605.1, TR601.6 (D+); also elsewhere on the board
PRIMARY-SWTEN: R606.1, R607.2; also elsewhere on the board
PRIMARY-WDT: R608.1; also elsewhere on the board


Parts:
C701, C702: 100pF, 15%, 25V; 0603
C703, C704: 1uF, 20%, 25V; 0603
LSP701, LSP702, LSP703, LSP704: PAD_2.0X1.5MM; PAD2.0X1.5MM
R701, R707: 0R; 0603
R702: 806, 1%, 1/10W; 0603
R703: 1.21k, 1%, 1/10W; 0603
R704, R705: 120R, 1%, 1/10W; 0603
R706: OPT: 0R; 0603
R708: 1M, 10%, 1/10W; 0603
TR701: HX1188NL; TR_SMD_SOIC-16_(12,70MMX9,53MMX5,97MM)_R_PULSE_REV01

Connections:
+5.0V_VREG_1: R701.2, R706.2, R708.2; also elsewhere on the board
FUSED_VBAT-: C701.1, C702.1, R703.2, R707.1; also elsewhere on the board
GND_1: C703.1, C704.1; also elsewhere on the board
unnamed: C701.2, TR701.2 (CT)
unnamed: C702.2, TR701.7 (CT)
unnamed: C704.2, TR701.15 (CMT)
unnamed: C703.2, TR701.10 (CMT)
SECONDARY-IBIAS: R702.1; also elsewhere on the board
SECONDARY-ICMP: R702.2, R703.1; also elsewhere on the board
SECONDARY-IN+_P: LSP701.P$1, TR701.16 (X+); also elsewhere on the board
SECONDARY-IN-_N: LSP702.P$1, TR701.14 (X-); also elsewhere on the board
SECONDARY-IN_N: R704.2, TR701.3 (D-); also elsewhere on the board
SECONDARY-IN_P: R704.1, TR701.1 (D+); also elsewhere on the board
SECONDARY-ISOMD: R701.1; also elsewhere on the board
SECONDARY-OUT+_P: LSP703.P$1, TR701.11 (X+); also elsewhere on the board
SECONDARY-OUT-_N: LSP704.P$1, TR701.9 (X-); also elsewhere on the board
SECONDARY-OUT_N: R705.2, TR701.8 (D-); also elsewhere on the board
SECONDARY-OUT_P: R705.1, TR701.6 (D+); also elsewhere on the board
SECONDARY-SWTEN: R706.1, R707.2; also elsewhere on the board
SECONDARY-WDT: R708.1; also elsewhere on the board

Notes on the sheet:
standard = off


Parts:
C801, C802, C803, C804, C805, C806, C807, C815, C816, C817, C818, C819, C820: 10nF, 100V, 10%; 0603
C808, C809, C810, C811, C812, C813, C814, C821, C822, C823, C824, C825, C826: OPT: 100nF, 25V; 0805
R801, R802, R803, R804, R805, R806, R807, R808, R809, R810, R811, R812, R813: 100R, 1%, 1/10W; 0603
Z801, Z802, Z803, Z804, Z805, Z806, Z807, Z808, Z809, Z810, Z811, Z812, Z813: 6.8V, 500mW; D_SMD_SOD-123_R_ON_REV01

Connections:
FUSED_CELL_0+: R806.1; also elsewhere on the board
FUSED_CELL_0-: R807.1; also elsewhere on the board
FUSED_CELL_1+: R805.1; also elsewhere on the board
FUSED_CELL_2+: R804.1; also elsewhere on the board
FUSED_CELL_3+: R803.1; also elsewhere on the board
FUSED_CELL_4+: R802.1; also elsewhere on the board
FUSED_CELL_5+: R801.1; also elsewhere on the board
FUSED_CELL_6+: R813.1; also elsewhere on the board
FUSED_CELL_7+: R812.1; also elsewhere on the board
FUSED_CELL_8+: R811.1; also elsewhere on the board
FUSED_CELL_9+: R810.1; also elsewhere on the board
FUSED_CELL_10+: R809.1; also elsewhere on the board
FUSED_CELL_11+: R808.1; also elsewhere on the board
FUSED_VBAT-: C801.2, C802.2, C803.2, C804.2, C805.2, C806.2, C807.2, C814.1, C815.2, C816.2, C817.2, C818.2, C819.2, C820.2, Z807.A; also elsewhere on the board
PRIMARY-C0: C807.1, C813.1, C814.2, R807.2, Z806.A, Z807.K (C); also elsewhere on the board
PRIMARY-C1: C806.1, C812.1, C813.2, R806.2, Z805.A, Z806.K (C); also elsewhere on the board
PRIMARY-C2: C805.1, C811.1, C812.2, R805.2, Z804.A, Z805.K (C); also elsewhere on the board
PRIMARY-C3: C804.1, C810.1, C811.2, R804.2, Z803.A, Z804.K (C); also elsewhere on the board
PRIMARY-C4: C803.1, C809.1, C810.2, R803.2, Z802.A, Z803.K (C); also elsewhere on the board
PRIMARY-C5: C802.1, C808.1, C809.2, R802.2, Z801.A, Z802.K (C); also elsewhere on the board
PRIMARY-C6: C801.1, C808.2, C826.1, R801.2, Z801.K (C), Z813.A; also elsewhere on the board
PRIMARY-C7: C820.1, C825.1, C826.2, R813.2, Z812.A, Z813.K (C); also elsewhere on the board
PRIMARY-C8: C819.1, C824.1, C825.2, R812.2, Z811.A, Z812.K (C); also elsewhere on the board
PRIMARY-C9: C818.1, C823.1, C824.2, R811.2, Z810.A, Z811.K (C); also elsewhere on the board
PRIMARY-C10: C817.1, C822.1, C823.2, R810.2, Z809.A, Z810.K (C); also elsewhere on the board
PRIMARY-C11: C816.1, C821.1, C822.2, R809.2, Z808.A, Z809.K (C); also elsewhere on the board
PRIMARY-C12: C815.1, C821.2, R808.2, Z808.K (C); also elsewhere on the board


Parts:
C901, C902, C903, C904, C905, C906, C907, C915, C916, C917, C918, C919, C920: 10nF, 100V, 10%; 0603
C908, C909, C910, C911, C912, C913, C914, C921, C922, C923, C924, C925, C926: OPT: 100nF, 25V; 0805
R901, R902, R903, R904, R905, R906, R907, R908, R909, R910, R911, R912, R913: 100R, 1%, 1/10W; 0603
Z901, Z902, Z903, Z904, Z905, Z906, Z907, Z908, Z909, Z910, Z911, Z912, Z913: 6.8V, 500mW; D_SMD_SOD-123_R_ON_REV01

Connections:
FUSED_CELL_0+: R906.1; also elsewhere on the board
FUSED_CELL_0-: R907.1; also elsewhere on the board
FUSED_CELL_1+: R905.1; also elsewhere on the board
FUSED_CELL_2+: R904.1; also elsewhere on the board
FUSED_CELL_3+: R903.1; also elsewhere on the board
FUSED_CELL_4+: R902.1; also elsewhere on the board
FUSED_CELL_5+: R901.1; also elsewhere on the board
FUSED_CELL_6+: R913.1; also elsewhere on the board
FUSED_CELL_7+: R912.1; also elsewhere on the board
FUSED_CELL_8+: R911.1; also elsewhere on the board
FUSED_CELL_9+: R910.1; also elsewhere on the board
FUSED_CELL_10+: R909.1; also elsewhere on the board
FUSED_CELL_11+: R908.1; also elsewhere on the board
FUSED_VBAT-: C901.2, C902.2, C903.2, C904.2, C905.2, C906.2, C907.2, C914.1, C915.2, C916.2, C917.2, C918.2, C919.2, C920.2, Z907.A; also elsewhere on the board
SECONDARY-C0: C907.1, C913.1, C914.2, R907.2, Z906.A, Z907.K (C); also elsewhere on the board
SECONDARY-C1: C906.1, C912.1, C913.2, R906.2, Z905.A, Z906.K (C); also elsewhere on the board
SECONDARY-C2: C905.1, C911.1, C912.2, R905.2, Z904.A, Z905.K (C); also elsewhere on the board
SECONDARY-C3: C904.1, C910.1, C911.2, R904.2, Z903.A, Z904.K (C); also elsewhere on the board
SECONDARY-C4: C903.1, C909.1, C910.2, R903.2, Z902.A, Z903.K (C); also elsewhere on the board
SECONDARY-C5: C902.1, C908.1, C909.2, R902.2, Z901.A, Z902.K (C); also elsewhere on the board
SECONDARY-C6: C901.1, C908.2, C926.1, R901.2, Z901.K (C), Z913.A; also elsewhere on the board
SECONDARY-C7: C920.1, C925.1, C926.2, R913.2, Z912.A, Z913.K (C); also elsewhere on the board
SECONDARY-C8: C919.1, C924.1, C925.2, R912.2, Z911.A, Z912.K (C); also elsewhere on the board
SECONDARY-C9: C918.1, C923.1, C924.2, R911.2, Z910.A, Z911.K (C); also elsewhere on the board
SECONDARY-C10: C917.1, C922.1, C923.2, R910.2, Z909.A, Z910.K (C); also elsewhere on the board
SECONDARY-C11: C916.1, C921.1, C922.2, R909.2, Z908.A, Z909.K (C); also elsewhere on the board
SECONDARY-C12: C915.1, C921.2, R908.2, Z908.K (C); also elsewhere on the board

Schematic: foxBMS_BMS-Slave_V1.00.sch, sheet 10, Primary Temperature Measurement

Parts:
C1001: 100nF, 20%, 16V; 0603
C1002, C1003, C1004: 1uF, 20%, 16V; 0603
C1005: 10nF, 20%, 16V; 0603
M1001, M1002: LTC1380CGN; IC_SMD_SSOP-16_(GN16)_R_LINEAR_REV01
O1001: LTC6255CS6; IC_SMD_TSOT-23-6_(S6)_R_LINEAR_REV01
R1001, R1002, R1003, R1004, R1005, R1006, R1007, R1008, R1009, R1010, R1011, R1012, R1013, R1014, R1015, R1016: 20k, 1%, 1/10W; 0603
R1017, R1018: 4.7k, 10%, 1/10W; 0603
R1019, R1021, R1023: N/A; 0603
R1020, R1022, R1024: 0R; 0603
R1025: 100R, 1%, 1/10W; 0603
SJ1001: OPT; SJ

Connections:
+3.0V_VREF2_0: C1001.2, R1001.2, R1002.2, R1003.2, R1004.2, R1005.2, R1006.2, R1007.2, R1008.2, R1009.2, R1010.2, R1011.2, R1012.2, R1013.2, R1014.2, R1015.2, R1016.2; also elsewhere on the board
+5.0V_VREG_0: C1002.2, C1003.2, C1004.2, M1001.16 (VCC), M1002.13 (A0), M1002.16 (VCC), O1001.6 (V+), R1017.2, R1018.2; also elsewhere on the board
FUSED_VBAT-: C1001.1, C1002.1, C1003.1, C1004.1, C1005.1, M1001.10 (VEE), M1001.11 (GND), M1001.12 (A1), M1001.13 (A0), M1002.10 (VEE), M1002.11 (GND), M1002.12 (A1), O1001.2 (V-); also elsewhere on the board
unnamed: O1001.1 (VOUT), O1001.4 (-), R1025.1
unnamed: O1001.5 (!SHDN), SJ1001.1
PRIMARY-GPIO0: R1023.2, R1024.2; also elsewhere on the board
PRIMARY-GPIO0-OPT: R1023.1; also elsewhere on the board
PRIMARY-GPIO2: SJ1001.2; also elsewhere on the board
PRIMARY-GPIO3: R1021.2, R1022.2; also elsewhere on the board
PRIMARY-GPIO3-OPT: R1021.1; also elsewhere on the board
PRIMARY-GPIO4: R1019.2, R1020.2; also elsewhere on the board
PRIMARY-GPIO4-OPT: R1019.1; also elsewhere on the board
PRIMARY-MUX-DATA: C1005.2, R1024.1, R1025.2
PRIMARY-OPA_IN: M1001.9 (DO), M1002.9 (DO), O1001.3 (+); also elsewhere on the board
PRIMARY-SCL: M1001.15 (SCL), M1002.15 (SCL), R1017.1, R1020.1; also elsewhere on the board
PRIMARY-SDA: M1001.14 (SDA), M1002.14 (SDA), R1018.1, R1022.1; also elsewhere on the board
T-SENSOR_0: M1001.1 (S0), R1015.1; also elsewhere on the board
T-SENSOR_1: M1001.2 (S1), R1013.1; also elsewhere on the board
T-SENSOR_2: M1001.3 (S2), R1011.1; also elsewhere on the board
T-SENSOR_3: M1001.4 (S3), R1009.1; also elsewhere on the board
T-SENSOR_4: M1001.5 (S4), R1007.1; also elsewhere on the board
T-SENSOR_5: M1001.6 (S5), R1005.1; also elsewhere on the board
T-SENSOR_6: M1001.7 (S6), R1003.1; also elsewhere on the board
T-SENSOR_7: M1001.8 (S7), R1001.1; also elsewhere on the board
T-SENSOR_8: M1002.1 (S0), R1016.1; also elsewhere on the board
T-SENSOR_9: M1002.2 (S1), R1014.1; also elsewhere on the board
T-SENSOR_10: M1002.3 (S2), R1012.1; also elsewhere on the board
T-SENSOR_11: M1002.4 (S3), R1010.1; also elsewhere on the board
T-SENSOR_12: M1002.5 (S4), R1008.1; also elsewhere on the board
T-SENSOR_13: M1002.6 (S5), R1006.1; also elsewhere on the board
T-SENSOR_14: M1002.7 (S6), R1004.1; also elsewhere on the board
T-SENSOR_15: M1002.8 (S7), R1002.1; also elsewhere on the board

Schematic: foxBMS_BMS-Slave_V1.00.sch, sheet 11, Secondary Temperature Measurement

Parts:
C1101: 100nF, 20%, 16V; 0603
C1102, C1103, C1104: 1uF, 20%, 16V; 0603
C1105: 10nF, 20%, 16V; 0603
M1101, M1102: LTC1380CGN; IC_SMD_SSOP-16_(GN16)_R_LINEAR_REV01
O1101: LTC6255CS6; IC_SMD_TSOT-23-6_(S6)_R_LINEAR_REV01
R1101, R1102, R1103, R1104, R1105, R1106, R1107, R1108, R1109, R1110, R1111, R1112, R1113, R1114, R1115, R1116: 20k, 1%, 1/10W; 0603
R1117, R1118: 4.7k, 10%, 1/10W; 0603
R1119, R1121, R1123: OPT: 0R; 0603
R1120, R1122, R1124: 0R; 0603
R1125: 100R, 1%, 1/10W; 0603
SJ1101: OPT; SJ

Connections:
+3.0V_VREF2_1: C1101.2, R1101.2, R1102.2, R1103.2, R1104.2, R1105.2, R1106.2, R1107.2, R1108.2, R1109.2, R1110.2, R1111.2, R1112.2, R1113.2, R1114.2, R1115.2, R1116.2; also elsewhere on the board
+5.0V_VREG_1: C1102.2, C1103.2, C1104.2, M1101.16 (VCC), M1102.13 (A0), M1102.16 (VCC), O1101.6 (V+), R1117.2, R1118.2; also elsewhere on the board
FUSED_VBAT-: C1101.1, C1102.1, C1103.1, C1104.1, C1105.1, M1101.10 (VEE), M1101.11 (GND), M1101.12 (A1), M1101.13 (A0), M1102.10 (VEE), M1102.11 (GND), M1102.12 (A1), O1101.2 (V-); also elsewhere on the board
unnamed: O1101.5 (!SHDN), SJ1101.1
unnamed: O1101.1 (VOUT), O1101.4 (-), R1125.1
SECONDARY-GPIO0: R1123.2, R1124.2; also elsewhere on the board
SECONDARY-GPIO0-OPT: R1123.1; also elsewhere on the board
SECONDARY-GPIO2: SJ1101.2; also elsewhere on the board
SECONDARY-GPIO3: R1121.2, R1122.2; also elsewhere on the board
SECONDARY-GPIO3-OPT: R1121.1; also elsewhere on the board
SECONDARY-GPIO4: R1119.2, R1120.2; also elsewhere on the board
SECONDARY-GPIO4-OPT: R1119.1; also elsewhere on the board
SECONDARY-MUX-DATA: C1105.2, R1124.1, R1125.2
SECONDARY-OPA_IN: M1101.9 (DO), M1102.9 (DO), O1101.3 (+); also elsewhere on the board
SECONDARY-SCL: M1101.15 (SCL), M1102.15 (SCL), R1117.1, R1120.1; also elsewhere on the board
SECONDARY-SDA: M1101.14 (SDA), M1102.14 (SDA), R1118.1, R1122.1; also elsewhere on the board
T-SENSOR_16: M1101.1 (S0), R1115.1; also elsewhere on the board
T-SENSOR_17: M1101.2 (S1), R1113.1; also elsewhere on the board
T-SENSOR_18: M1101.3 (S2), R1111.1; also elsewhere on the board
T-SENSOR_19: M1101.4 (S3), R1109.1; also elsewhere on the board
T-SENSOR_20: M1101.5 (S4), R1107.1; also elsewhere on the board
T-SENSOR_21: M1101.6 (S5), R1105.1; also elsewhere on the board
T-SENSOR_22: M1101.7 (S6), R1103.1; also elsewhere on the board
T-SENSOR_23: M1101.8 (S7), R1101.1; also elsewhere on the board
T-SENSOR_24: M1102.1 (S0), R1116.1; also elsewhere on the board
T-SENSOR_25: M1102.2 (S1), R1114.1; also elsewhere on the board
T-SENSOR_26: M1102.3 (S2), R1112.1; also elsewhere on the board
T-SENSOR_27: M1102.4 (S3), R1110.1; also elsewhere on the board
T-SENSOR_28: M1102.5 (S4), R1108.1; also elsewhere on the board
T-SENSOR_29: M1102.6 (S5), R1106.1; also elsewhere on the board
T-SENSOR_30: M1102.7 (S6), R1104.1; also elsewhere on the board
T-SENSOR_31: M1102.8 (S7), R1102.1; also elsewhere on the board

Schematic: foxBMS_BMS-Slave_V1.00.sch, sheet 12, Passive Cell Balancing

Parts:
R1201, R1202, R1203, R1204, R1205, R1206, R1207, R1208, R1209, R1210, R1211, R1212, R1219, R1220, R1221, R1222, R1223, R1224, R1225, R1226, R1227, R1228, R1229, R1230: 75R, 10%, 0.4W; 2010
R1213, R1214, R1215, R1216, R1217, R1218, R1231, R1232, R1233, R1234, R1235, R1236: 3.3k, 10%, 1/10W; 0603
T1201, T1202, T1203, T1204, T1205, T1206, T1207, T1208, T1209, T1210, T1211, T1212: NX2301P; D_SMD_SOT23_(TO-236AB)_R_NXP_REV01

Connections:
CELL0_FEEDBACK+: R1206.2, R1212.2, T1206.3 (D); also elsewhere on the board
CELL1_FEEDBACK+: R1205.2, R1211.2, T1205.3 (D); also elsewhere on the board
CELL2_FEEDBACK+: R1204.2, R1210.2, T1204.3 (D); also elsewhere on the board
CELL3_FEEDBACK+: R1203.2, R1209.2, T1203.3 (D); also elsewhere on the board
CELL4_FEEDBACK+: R1202.2, R1208.2, T1202.3 (D); also elsewhere on the board
CELL5_FEEDBACK+: R1201.2, R1207.2, T1201.3 (D); also elsewhere on the board
CELL6_FEEDBACK+: R1224.2, R1230.2, T1212.3 (D); also elsewhere on the board
CELL7_FEEDBACK+: R1223.2, R1229.2, T1211.3 (D); also elsewhere on the board
CELL8_FEEDBACK+: R1222.2, R1228.2, T1210.3 (D); also elsewhere on the board
CELL9_FEEDBACK+: R1221.2, R1227.2, T1209.3 (D); also elsewhere on the board
CELL10_FEEDBACK+: R1220.2, R1226.2, T1208.3 (D); also elsewhere on the board
CELL11_FEEDBACK+: R1219.2, R1225.2, T1207.3 (D); also elsewhere on the board
FUSED_CELL_0+: R1205.1, R1211.1, T1206.2 (S); also elsewhere on the board
FUSED_CELL_1+: R1204.1, R1210.1, T1205.2 (S); also elsewhere on the board
FUSED_CELL_2+: R1203.1, R1209.1, T1204.2 (S); also elsewhere on the board
FUSED_CELL_3+: R1202.1, R1208.1, T1203.2 (S); also elsewhere on the board
FUSED_CELL_4+: R1201.1, R1207.1, T1202.2 (S); also elsewhere on the board
FUSED_CELL_5+: R1224.1, R1230.1, T1201.2 (S); also elsewhere on the board
FUSED_CELL_6+: R1223.1, R1229.1, T1212.2 (S); also elsewhere on the board
FUSED_CELL_7+: R1222.1, R1228.1, T1211.2 (S); also elsewhere on the board
FUSED_CELL_8+: R1221.1, R1227.1, T1210.2 (S); also elsewhere on the board
FUSED_CELL_9+: R1220.1, R1226.1, T1209.2 (S); also elsewhere on the board
FUSED_CELL_10+: R1219.1, R1225.1, T1208.2 (S); also elsewhere on the board
FUSED_CELL_11+: T1207.2 (S); also elsewhere on the board
FUSED_VBAT-: R1206.1, R1212.1; also elsewhere on the board
unnamed: R1218.1, T1206.1 (G)
unnamed: R1216.1, T1205.1 (G)
unnamed: R1217.1, T1204.1 (G)
unnamed: R1215.1, T1203.1 (G)
unnamed: R1214.1, T1202.1 (G)
unnamed: R1213.1, T1201.1 (G)
unnamed: R1232.1, T1212.1 (G)
unnamed: R1236.1, T1211.1 (G)
unnamed: R1235.1, T1210.1 (G)
unnamed: R1234.1, T1209.1 (G)
unnamed: R1233.1, T1208.1 (G)
unnamed: R1231.1, T1207.1 (G)
S0: R1218.2; also elsewhere on the board
S1: R1216.2; also elsewhere on the board
S2: R1217.2; also elsewhere on the board
S3: R1215.2; also elsewhere on the board
S4: R1214.2; also elsewhere on the board
S5: R1213.2; also elsewhere on the board
S6: R1232.2; also elsewhere on the board
S7: R1236.2; also elsewhere on the board
S8: R1235.2; also elsewhere on the board
S9: R1234.2; also elsewhere on the board
S10: R1233.2; also elsewhere on the board
S11: R1231.2; also elsewhere on the board

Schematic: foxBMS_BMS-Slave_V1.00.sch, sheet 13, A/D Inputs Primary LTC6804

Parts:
C1301, C1302: 1uF, 20%, 16V; 0603
M1301, M1302: LTC1380CGN; IC_SMD_SSOP-16_(GN16)_R_LINEAR_REV01
R1301, R1302, R1303, R1304, R1305, R1306, R1307, R1308, R1309, R1310, R1311, R1312, R1313, R1314, R1315, R1316: 10k, 10%, 1/10W; 0603

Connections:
+5.0V_VREG_0: C1301.2, C1302.2, M1301.12 (A1), M1301.16 (VCC), M1302.12 (A1), M1302.13 (A0), M1302.16 (VCC); also elsewhere on the board
FUSED_VBAT-: C1301.1, C1302.1, M1301.10 (VEE), M1301.11 (GND), M1301.13 (A0), M1302.10 (VEE), M1302.11 (GND), R1301.2, R1302.2, R1303.2, R1304.2, R1305.2, R1306.2, R1307.2, R1308.2, R1309.2, R1310.2, R1311.2, R1312.2, R1313.2, R1314.2, R1315.2, R1316.2; also elsewhere on the board
PRIMARY-OPA_IN: M1301.9 (DO), M1302.9 (DO); also elsewhere on the board
PRIMARY-SCL: M1301.15 (SCL), M1302.15 (SCL); also elsewhere on the board
PRIMARY-SDA: M1301.14 (SDA), M1302.14 (SDA); also elsewhere on the board
PRIMARY_D/A_INPUT_0: M1301.1 (S0), R1301.1; also elsewhere on the board
PRIMARY_D/A_INPUT_1: M1301.2 (S1), R1302.1; also elsewhere on the board
PRIMARY_D/A_INPUT_2: M1301.3 (S2), R1303.1; also elsewhere on the board
PRIMARY_D/A_INPUT_3: M1301.4 (S3), R1304.1; also elsewhere on the board
PRIMARY_D/A_INPUT_4: M1301.5 (S4), R1305.1; also elsewhere on the board
PRIMARY_D/A_INPUT_5: M1301.6 (S5), R1306.1; also elsewhere on the board
PRIMARY_D/A_INPUT_6: M1301.7 (S6), R1307.1; also elsewhere on the board
PRIMARY_D/A_INPUT_7: M1301.8 (S7), R1308.1; also elsewhere on the board
PRIMARY_D/A_INPUT_8: M1302.1 (S0), R1309.1; also elsewhere on the board
PRIMARY_D/A_INPUT_9: M1302.2 (S1), R1310.1; also elsewhere on the board
PRIMARY_D/A_INPUT_10: M1302.3 (S2), R1311.1; also elsewhere on the board
PRIMARY_D/A_INPUT_11: M1302.4 (S3), R1312.1; also elsewhere on the board
PRIMARY_D/A_INPUT_12: M1302.5 (S4), R1313.1; also elsewhere on the board
PRIMARY_D/A_INPUT_13: M1302.6 (S5), R1314.1; also elsewhere on the board
PRIMARY_D/A_INPUT_14: M1302.7 (S6), R1315.1; also elsewhere on the board
PRIMARY_D/A_INPUT_15: M1302.8 (S7), R1316.1; also elsewhere on the board

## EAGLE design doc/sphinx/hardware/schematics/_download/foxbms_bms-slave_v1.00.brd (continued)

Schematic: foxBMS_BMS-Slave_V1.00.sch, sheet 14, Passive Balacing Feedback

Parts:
C1401, C1402: 1uF, 20%, 16V; 0603
IC1401, IC1402, IC1403, IC1404, IC1405, IC1406, IC1407, IC1408, IC1409, IC1410, IC1411, IC1412: CPC1008N; K_SMD_SOP-4_R_IXYS_REV01
M1401, M1402: LTC1380CGN; IC_SMD_SSOP-16_(GN16)_R_LINEAR_REV01
R1401, R1402, R1403, R1404, R1405, R1406, R1408, R1409, R1410, R1411, R1412, R1413: 130, 10%, 1/10W; 0603
R1407: 1k, 10%, 1/10W; 0603
R1414, R1415, R1416, R1417, R1418, R1419, R1420, R1421, R1422, R1423, R1424, R1425, R1426, R1427, R1428, R1429: 10k, 10%, 1/10W; 0603

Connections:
+5.0V_VREG_1: C1401.2, C1402.2, M1401.12 (A1), M1401.16 (VCC), M1402.12 (A1), M1402.13 (A0), M1402.16 (VCC), R1407.1; also elsewhere on the board
CELL0_FEEDBACK: IC1406.3, M1401.1 (S0), R1414.1
CELL0_FEEDBACK+: R1406.2; also elsewhere on the board
CELL1_FEEDBACK: IC1405.3, M1401.2 (S1), R1415.1
CELL1_FEEDBACK+: R1405.2; also elsewhere on the board
CELL2_FEEDBACK: IC1404.3, M1401.3 (S2), R1416.1
CELL2_FEEDBACK+: R1404.2; also elsewhere on the board
CELL3_FEEDBACK: IC1403.3, M1401.4 (S3), R1417.1
CELL3_FEEDBACK+: R1403.2; also elsewhere on the board
CELL4_FEEDBACK: IC1402.3, M1401.5 (S4), R1418.1
CELL4_FEEDBACK+: R1402.2; also elsewhere on the board
CELL5_FEEDBACK: IC1401.3, M1401.6 (S5), R1419.1
CELL5_FEEDBACK+: R1401.2; also elsewhere on the board
CELL6_FEEDBACK: IC1412.3, M1401.7 (S6), R1420.1
CELL6_FEEDBACK+: R1413.2; also elsewhere on the board
CELL7_FEEDBACK: IC1411.3, M1401.8 (S7), R1421.1
CELL7_FEEDBACK+: R1412.2; also elsewhere on the board
CELL8_FEEDBACK: IC1410.3, M1402.1 (S0), R1422.1
CELL8_FEEDBACK+: R1411.2; also elsewhere on the board
CELL9_FEEDBACK: IC1409.3, M1402.2 (S1), R1423.1
CELL9_FEEDBACK+: R1410.2; also elsewhere on the board
CELL10_FEEDBACK: IC1408.3, M1402.3 (S2), R1424.1
CELL10_FEEDBACK+: R1409.2; also elsewhere on the board
CELL11_FEEDBACK: IC1407.3, M1402.4 (S3), R1425.1
CELL11_FEEDBACK+: R1408.2; also elsewhere on the board
FUSED_CELL_0+: IC1405.2 (CON-); also elsewhere on the board
FUSED_CELL_1+: IC1404.2 (CON-); also elsewhere on the board
FUSED_CELL_2+: IC1403.2 (CON-); also elsewhere on the board
FUSED_CELL_3+: IC1402.2 (CON-); also elsewhere on the board
FUSED_CELL_4+: IC1401.2 (CON-); also elsewhere on the board
FUSED_CELL_5+: IC1412.2 (CON-); also elsewhere on the board
FUSED_CELL_6+: IC1411.2 (CON-); also elsewhere on the board
FUSED_CELL_7+: IC1410.2 (CON-); also elsewhere on the board
FUSED_CELL_8+: IC1409.2 (CON-); also elsewhere on the board
FUSED_CELL_9+: IC1408.2 (CON-); also elsewhere on the board
FUSED_CELL_10+: IC1407.2 (CON-); also elsewhere on the board
FUSED_VBAT-: C1401.1, C1402.1, IC1406.2 (CON-), M1401.10 (VEE), M1401.11 (GND), M1401.13 (A0), M1402.10 (VEE), M1402.11 (GND), R1414.2, R1415.2, R1416.2, R1417.2, R1418.2, R1419.2, R1420.2, R1421.2, R1422.2, R1423.2, R1424.2, R1425.2, R1426.2, R1427.2, R1428.2, R1429.2; also elsewhere on the board
unnamed: IC1401.4, IC1402.4, IC1403.4, IC1404.4, IC1405.4, IC1406.4, IC1407.4, IC1408.4, IC1409.4, IC1410.4, IC1411.4, IC1412.4, R1407.2
unnamed: IC1402.1 (CON+), R1402.1
unnamed: IC1403.1 (CON+), R1403.1
unnamed: IC1404.1 (CON+), R1404.1
unnamed: IC1408.1 (CON+), R1409.1
unnamed: IC1409.1 (CON+), R1410.1
unnamed: IC1405.1 (CON+), R1405.1
unnamed: IC1407.1 (CON+), R1408.1
unnamed: IC1410.1 (CON+), R1411.1
unnamed: IC1411.1 (CON+), R1412.1
unnamed: IC1406.1 (CON+), R1406.1
unnamed: IC1412.1 (CON+), R1413.1
unnamed: IC1401.1 (CON+), R1401.1
SECONDARY-OPA_IN: M1401.9 (DO), M1402.9 (DO); also elsewhere on the board
SECONDARY-SCL: M1401.15 (SCL), M1402.15 (SCL); also elsewhere on the board
SECONDARY-SDA: M1401.14 (SDA), M1402.14 (SDA); also elsewhere on the board
SECONDARY_D/A_INPUT_0: M1402.5 (S4), R1426.1; also elsewhere on the board
SECONDARY_D/A_INPUT_1: M1402.6 (S5), R1427.1; also elsewhere on the board
SECONDARY_D/A_INPUT_2: M1402.7 (S6), R1428.1; also elsewhere on the board
SECONDARY_D/A_INPUT_3: M1402.8 (S7), R1429.1; also elsewhere on the board

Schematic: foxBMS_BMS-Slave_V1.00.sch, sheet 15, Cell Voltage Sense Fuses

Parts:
F1501, F1515: 0.5A, 63V, 0.25R; 1206
F1502, F1503, F1504, F1505, F1506, F1507, F1508, F1509, F1510, F1511, F1512, F1513, F1514: FUSE: 0.250A, 32V, 0.57R; 0603
LSP1501, LSP1502, LSP1503, LSP1504, LSP1505, LSP1506, LSP1507, LSP1508, LSP1509, LSP1510, LSP1511, LSP1512, LSP1513, LSP1514, LSP1515: PAD_2.0X1.5MM; PAD2.0X1.5MM
SJ1501, SJ1502: SJ

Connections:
CELL_0+: F1503.1; also elsewhere on the board
CELL_0-: F1502.1, SJ1501.1; also elsewhere on the board
CELL_1+: F1504.1; also elsewhere on the board
CELL_2+: F1505.1; also elsewhere on the board
CELL_3+: F1506.1; also elsewhere on the board
CELL_4+: F1507.1; also elsewhere on the board
CELL_5+: F1508.1; also elsewhere on the board
CELL_6+: F1509.1; also elsewhere on the board
CELL_7+: F1510.1; also elsewhere on the board
CELL_8+: F1511.1; also elsewhere on the board
CELL_9+: F1512.1; also elsewhere on the board
CELL_10+: F1513.1; also elsewhere on the board
CELL_11+: F1514.1, SJ1502.2; also elsewhere on the board
FUSED_CELL_0+: F1503.2, LSP1503.P$1; also elsewhere on the board
FUSED_CELL_0-: F1502.2, LSP1502.P$1; also elsewhere on the board
FUSED_CELL_1+: F1504.2, LSP1504.P$1; also elsewhere on the board
FUSED_CELL_2+: F1505.2, LSP1505.P$1; also elsewhere on the board
FUSED_CELL_3+: F1506.2, LSP1506.P$1; also elsewhere on the board
FUSED_CELL_4+: F1507.2, LSP1507.P$1; also elsewhere on the board
FUSED_CELL_5+: F1508.2, LSP1508.P$1; also elsewhere on the board
FUSED_CELL_6+: F1509.2, LSP1509.P$1; also elsewhere on the board
FUSED_CELL_7+: F1510.2, LSP1510.P$1; also elsewhere on the board
FUSED_CELL_8+: F1511.2, LSP1511.P$1; also elsewhere on the board
FUSED_CELL_9+: F1512.2, LSP1512.P$1; also elsewhere on the board
FUSED_CELL_10+: F1513.2, LSP1513.P$1; also elsewhere on the board
FUSED_CELL_11+: F1514.2, LSP1514.P$1; also elsewhere on the board
FUSED_VBAT+: F1515.2, LSP1515.P$1; also elsewhere on the board
FUSED_VBAT-: F1501.2, LSP1501.P$1; also elsewhere on the board
VBAT+: F1515.1, SJ1502.1; also elsewhere on the board
VBAT-: F1501.1, SJ1501.2; also elsewhere on the board

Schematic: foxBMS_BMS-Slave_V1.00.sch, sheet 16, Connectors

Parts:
X1601, X1602: 43045-0406_MOLEX_4PIN; X_SMD_MOLEX_43045-0408_R_REV01
X1603: 43045-1606_MOLEX_16PIN; X_SMD_MOLEX_43045-1608_R_REV01
X1604, X1607, X1608: MA10-2
X1605: MA09-2
X1606: 43045-2406_MOLEX_24PIN; X_SMD_MOLEX_43045-2408_R_REV01

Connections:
+3.0V_VREF2_0: X1604.18; also elsewhere on the board
+3.0V_VREF2_1: X1604.17; also elsewhere on the board
+5.0V_VREG_0: X1604.16; also elsewhere on the board
+5.0V_VREG_1: X1604.15; also elsewhere on the board
CELL_0+: X1603.2; also elsewhere on the board
CELL_0-: X1603.9; also elsewhere on the board
CELL_1+: X1603.10; also elsewhere on the board
CELL_2+: X1603.3; also elsewhere on the board
CELL_3+: X1603.11; also elsewhere on the board
CELL_4+: X1603.4; also elsewhere on the board
CELL_5+: X1603.12; also elsewhere on the board
CELL_6+: X1603.5; also elsewhere on the board
CELL_7+: X1603.13; also elsewhere on the board
CELL_8+: X1603.6; also elsewhere on the board
CELL_9+: X1603.14; also elsewhere on the board
CELL_10+: X1603.7; also elsewhere on the board
CELL_11+: X1603.15; also elsewhere on the board
FUSED_VBAT-: X1605.17, X1605.18, X1606.1, X1606.2, X1606.3, X1606.4, X1606.5, X1606.6, X1606.7, X1606.8, X1606.9, X1606.10, X1606.11, X1606.12, X1607.2, X1607.4, X1607.6, X1607.8, X1607.10, X1607.12, X1607.14, X1607.16, X1607.18, X1607.20, X1608.2, X1608.4, X1608.6, X1608.8, X1608.10, X1608.12, X1608.14, X1608.16, X1608.18, X1608.20; also elsewhere on the board
PRIMARY-GPIO0-OPT: X1604.6; also elsewhere on the board
PRIMARY-GPIO1: X1604.8; also elsewhere on the board
PRIMARY-GPIO2: X1604.10; also elsewhere on the board
PRIMARY-GPIO3-OPT: X1604.12; also elsewhere on the board
PRIMARY-GPIO4-OPT: X1604.14; also elsewhere on the board
PRIMARY-IN+_P: X1601.1; also elsewhere on the board
PRIMARY-IN-_N: X1601.3; also elsewhere on the board
PRIMARY-OUT+_P: X1601.4; also elsewhere on the board
PRIMARY-OUT-_N: X1601.2; also elsewhere on the board
PRIMARY-WDT: X1604.20; also elsewhere on the board
PRIMARY_D/A_INPUT_0: X1605.1; also elsewhere on the board
PRIMARY_D/A_INPUT_1: X1605.2; also elsewhere on the board
PRIMARY_D/A_INPUT_2: X1605.3; also elsewhere on the board
PRIMARY_D/A_INPUT_3: X1605.4; also elsewhere on the board
PRIMARY_D/A_INPUT_4: X1605.5; also elsewhere on the board
PRIMARY_D/A_INPUT_5: X1605.6; also elsewhere on the board
PRIMARY_D/A_INPUT_6: X1605.7; also elsewhere on the board
PRIMARY_D/A_INPUT_7: X1605.8; also elsewhere on the board
PRIMARY_D/A_INPUT_8: X1605.9; also elsewhere on the board
PRIMARY_D/A_INPUT_9: X1605.10; also elsewhere on the board
PRIMARY_D/A_INPUT_10: X1605.11; also elsewhere on the board
PRIMARY_D/A_INPUT_11: X1605.12; also elsewhere on the board
PRIMARY_D/A_INPUT_12: X1605.13; also elsewhere on the board
PRIMARY_D/A_INPUT_13: X1605.14; also elsewhere on the board
PRIMARY_D/A_INPUT_14: X1605.15; also elsewhere on the board
PRIMARY_D/A_INPUT_15: X1605.16; also elsewhere on the board
SECONDARY-GPIO0-OPT: X1604.5; also elsewhere on the board
SECONDARY-GPIO1: X1604.7; also elsewhere on the board
SECONDARY-GPIO2: X1604.9; also elsewhere on the board
SECONDARY-GPIO3-OPT: X1604.11; also elsewhere on the board
SECONDARY-GPIO4-OPT: X1604.13; also elsewhere on the board
SECONDARY-IN+_P: X1602.1; also elsewhere on the board
SECONDARY-IN-_N: X1602.3; also elsewhere on the board
SECONDARY-OUT+_P: X1602.4; also elsewhere on the board
SECONDARY-OUT-_N: X1602.2; also elsewhere on the board
SECONDARY-WDT: X1604.19; also elsewhere on the board
SECONDARY_D/A_INPUT_0: X1604.1; also elsewhere on the board
SECONDARY_D/A_INPUT_1: X1604.2; also elsewhere on the board
SECONDARY_D/A_INPUT_2: X1604.3; also elsewhere on the board
SECONDARY_D/A_INPUT_3: X1604.4; also elsewhere on the board
T-SENSOR_0: X1606.24; also elsewhere on the board
T-SENSOR_1: X1606.23; also elsewhere on the board
T-SENSOR_2: X1606.22; also elsewhere on the board
T-SENSOR_3: X1606.21; also elsewhere on the board
T-SENSOR_4: X1606.20; also elsewhere on the board
T-SENSOR_5: X1606.19; also elsewhere on the board
T-SENSOR_6: X1607.1; also elsewhere on the board
T-SENSOR_7: X1607.3; also elsewhere on the board
T-SENSOR_8: X1607.5; also elsewhere on the board
T-SENSOR_9: X1607.7; also elsewhere on the board
T-SENSOR_10: X1607.9; also elsewhere on the board
T-SENSOR_11: X1607.11; also elsewhere on the board
T-SENSOR_12: X1607.13; also elsewhere on the board
T-SENSOR_13: X1607.15; also elsewhere on the board
T-SENSOR_14: X1607.17; also elsewhere on the board
T-SENSOR_15: X1607.19; also elsewhere on the board
T-SENSOR_16: X1606.18; also elsewhere on the board
T-SENSOR_17: X1606.17; also elsewhere on the board
T-SENSOR_18: X1606.16; also elsewhere on the board
T-SENSOR_19: X1606.15; also elsewhere on the board
T-SENSOR_20: X1606.14; also elsewhere on the board
T-SENSOR_21: X1606.13; also elsewhere on the board
T-SENSOR_22: X1608.19; also elsewhere on the board
T-SENSOR_23: X1608.17; also elsewhere on the board
T-SENSOR_24: X1608.15; also elsewhere on the board
T-SENSOR_25: X1608.13; also elsewhere on the board
T-SENSOR_26: X1608.11; also elsewhere on the board
T-SENSOR_27: X1608.9; also elsewhere on the board
T-SENSOR_28: X1608.7; also elsewhere on the board
T-SENSOR_29: X1608.5; also elsewhere on the board
T-SENSOR_30: X1608.3; also elsewhere on the board
T-SENSOR_31: X1608.1; also elsewhere on the board
VBAT+: X1603.16; also elsewhere on the board
VBAT-: X1603.1; also elsewhere on the board

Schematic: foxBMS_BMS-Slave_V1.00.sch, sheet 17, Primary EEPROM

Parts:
C1701: 100nF, 20%, 16V; 0603
IC1701: 24AA02UID; IC_SMD_SOT23-5_R_MICROCHIP_REV01

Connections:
+5.0V_VREG_0: C1701.2, IC1701.4 (VCC); also elsewhere on the board
FUSED_VBAT-: C1701.1, IC1701.2 (VSS); also elsewhere on the board
PRIMARY-SCL: IC1701.1 (SCL); also elsewhere on the board
PRIMARY-SDA: IC1701.3 (SDA); also elsewhere on the board

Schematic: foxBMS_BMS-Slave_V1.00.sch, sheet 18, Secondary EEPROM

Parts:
C1801: 100nF, 20%, 16V; 0603
IC1801: 24AA02UID; IC_SMD_SOT23-5_R_MICROCHIP_REV01

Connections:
+5.0V_VREG_1: C1801.2, IC1801.4 (VCC); also elsewhere on the board
FUSED_VBAT-: C1801.1, IC1801.2 (VSS); also elsewhere on the board
SECONDARY-SCL: IC1801.1 (SCL); also elsewhere on the board
SECONDARY-SDA: IC1801.3 (SDA); also elsewhere on the board


Board: 6 copper layers, 120.0 x 110.0 mm, 391 parts (0 on the bottom side), 244 nets.

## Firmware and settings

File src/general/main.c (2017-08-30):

/**
 *
 * @copyright &copy; 2010 - 2017, Fraunhofer-Gesellschaft zur Foerderung der angewandten Forschung e.V. All rights reserved.
 *
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
 * THIS SOFTWARE IS PROVIDED BY THE COPYRIGHT HOLDERS AND CONTRIBUTORS "AS IS" AND ANY EXPRESS OR IMPLIED WARRANTIES, INCLUDING, BUT NOT LIMITED TO, THE IMPLIED WARRANTIES OF MERCHANTABILITY AND FITNESS FOR A PARTICULAR PURPOSE ARE DISCLAIMED. IN NO EVENT SHALL THE COPYRIGHT HOLDER OR CONTRIBUTORS BE LIABLE FOR ANY DIRECT, INDIRECT, INCIDENTAL, SPECIAL, EXEMPLARY, OR CONSEQUENTIAL DAMAGES (INCLUDING, BUT NOT LIMITED TO, PROCUREMENT OF SUBSTITUTE GOODS OR SERVICES; LOSS OF USE, DATA, OR PROFITS; OR BUSINESS INTERRUPTION) HOWEVER CAUSED AND ON ANY THEORY OF LIABILITY, WHETHER IN CONTRACT, STRICT LIABILITY, OR TORT (INCLUDING NEGLIGENCE OR OTHERWISE) ARISING IN ANY WAY OUT OF THE USE OF THIS SOFTWARE, EVEN IF ADVISED OF THE POSSIBILITY OF SUCH DAMAGE.
 *
 * We kindly request you to use one or more of the following phrases to refer to foxBMS in your hardware, software, documentation or advertising materials:
 *
 * &Prime;This product uses parts of foxBMS&reg;&Prime;
 *
 * &Prime;This product includes parts of foxBMS&reg;&Prime;
 *
 * &Prime;This product is derived from foxBMS&reg;&Prime;
 *
 */

/**
 * @file    main.c
 * @author  foxBMS Team
 * @date    26.08.2015 (date of creation)
 * @ingroup GENERAL
 * @prefix  none
 *
 * @brief   Main function
 *
 */


/*================== Includes =============================================*/
/* recommended include order of header files:
 * 
 * 1.    include general.h
 * 2.    include module's own header
 * 3...  other headers
 *
 */
#include "general.h"
#include "main.h"

#include "mcu_cfg.h"
#include "os.h"
#include "version.h"
#include "can.h"
#include "nvic.h"
#include "io.h"
#include "rcc.h"
#include "dma.h"
#include "spi.h"
#include "timer.h"
#include "led.h"
#include "adc.h"
#include "bkpsram.h"
#include "uart.h"
#include "com.h"
#include "chksum.h"
#include "diag.h"
#include "mcu.h"
#include "wdg.h"

/*================== Macros and Definitions ===============================*/


/*================== Constant and Variable Definitions ====================*/


/*================== Function Prototypes ==================================*/
void SystemClock_Config(void);
void BOOT_Init(void);

/*================== Function Implementations =============================*/
/**
  * @brief  Main program
  *
  * @return int
  *
  */
int main(void)
{
    HAL_Init();         /* STM32F4xx HAL library initialization */
    RTC_Init();
#if BUILD_MODULE_ENABLE_WATCHDOG
    WDG_Init();        /* initialize and start watchdog*/
#endif
    BKP_SRAM_Init();    // at this point diagnosis event memory in BKP_SRAM will be available
    SystemClock_Config();

    DIAG_Init(&diag_dev);
    BOOT_Init();
    IO_Init(&io_cfg[0]);

#if BUILD_MODULE_ENABLE_SAFETY_FEATURES == 0
    IO_TogglePin(LED_DEBUG_1);
    os_safety_state = OS_SAFETY_FEATURE_DISABLED;
#else
    os_safety_state = OS_SAFETY_FEATURE_ENABLED;
#endif

    DMA_Init(&dma_devices[0]);
    SPI_Init(&spi_devices[0]);
    TIM_Init();

#if BUILD_MODULE_ENABLE_UART
    UART_Init();
#endif

    NVIC_PreOsInit();
    LED_Init();
    ADC_Init(adc_devices);

    /* Initialize mutexes, events and tasks */
    OS_TaskInit();

    os_schedulerstarttime = osKernelSysTick();
  
    /* Initialize interrupts */
    NVIC_PreOsInit();

    if(CHK_Flashchecksum(&ver_sw_validation)==E_OK)
    {
        chk_status.checksumstatus = CHK_CHECKSUM_PASSED;
    }
    else
    {
        chk_status.checksumstatus = CHK_CHECKSUM_FAILED;
        if(DIAG_HANDLER_RETURN_OK != DIAG_Handler(DIAG_CH_FLASHCHECKSUM, DIAG_EVENT_NOK, 0, NULL))
        {
            ;
        }
    }

#if BUILD_MODULE_ENABLE_COM
    COM_StartupInfo();
#endif

    os_boot = OS_INIT_OSSTARTKERNEL;    // start scheduler
    osKernelStart();                    // osKernelStart() should never return 
    
    while(1)
    {
        ;
    }
    return 0;
}


void SystemClock_Config(void)
{
    RCC_ClockConfig();
}

/**
 * Set boot reset date, time and status
 *
 * @return void.
 */
void BOOT_Init(void)
{
    RTC_Time_s currTime;
    RTC_Date_s currDate;

    main_state.CSR = MCU_SystemResetStatus_Init();

    RTC_getTime(&currTime);
    RTC_getDate(&currDate);
    main_state.boot_rtcdate = currDate;      // set boot date and time
    main_state.boot_rtctime = currTime;
    main_state.resetcounter++;

    //@todo akdere: check diagnosis memory
}

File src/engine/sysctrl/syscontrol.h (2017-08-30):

/**
 *
 * @copyright &copy; 2010 - 2017, Fraunhofer-Gesellschaft zur Foerderung der angewandten Forschung e.V. All rights reserved.
 *
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
 * THIS SOFTWARE IS PROVIDED BY THE COPYRIGHT HOLDERS AND CONTRIBUTORS "AS IS" AND ANY EXPRESS OR IMPLIED WARRANTIES, INCLUDING, BUT NOT LIMITED TO, THE IMPLIED WARRANTIES OF MERCHANTABILITY AND FITNESS FOR A PARTICULAR PURPOSE ARE DISCLAIMED. IN NO EVENT SHALL THE COPYRIGHT HOLDER OR CONTRIBUTORS BE LIABLE FOR ANY DIRECT, INDIRECT, INCIDENTAL, SPECIAL, EXEMPLARY, OR CONSEQUENTIAL DAMAGES (INCLUDING, BUT NOT LIMITED TO, PROCUREMENT OF SUBSTITUTE GOODS OR SERVICES; LOSS OF USE, DATA, OR PROFITS; OR BUSINESS INTERRUPTION) HOWEVER CAUSED AND ON ANY THEORY OF LIABILITY, WHETHER IN CONTRACT, STRICT LIABILITY, OR TORT (INCLUDING NEGLIGENCE OR OTHERWISE) ARISING IN ANY WAY OUT OF THE USE OF THIS SOFTWARE, EVEN IF ADVISED OF THE POSSIBILITY OF SUCH DAMAGE.
 *
 * We kindly request you to use one or more of the following phrases to refer to foxBMS in your hardware, software, documentation or advertising materials:
 *
 * &Prime;This product uses parts of foxBMS&reg;&Prime;
 *
 * &Prime;This product includes parts of foxBMS&reg;&Prime;
 *
 * &Prime;This product is derived from foxBMS&reg;&Prime;
 *
 */

/**
 * @file    syscontrol.h
 * @author  foxBMS Team
 * @date    21.09.2015 (date of creation)
 * @ingroup ENGINE
 * @prefix  SYSCTRL
 *
 * @brief   Syscontrol driver header
 *
 * ==============================================================================
 *                  Purpose of the SYSCONTROL-module
 * ==============================================================================
 * The syscontrol module handles the requested state transitions from the
 * bmsctrl-module. Depending on the current state and substate of the battery
 * management system the sysctrl performs the state transition or denies it.
 * The syscontrol module manages the following main states
 *  - uninitialized BMS (SYSCTRL_STATE_UNINITIALIZED)
 *  - permission to initialize the BMS (SYSCTRL_STATE_INITIALIZING)
 *  - sleeping mode (SYSCTRL_STATE_SLEEP)
 *  - idle mode (SYSCTRL_STATE_IDLE)
 *  - standby mode (SYSCTRL_STATE_STANDBY)
 *  - normal mode (SYSCTRL_STATE_NORMAL)
 *  - general error state (SYSCTRL_STATE_ERROR)
 *  - and an error while precharging (SYSCTRL_STATE_PRECHARGE_ERROR)
 *
 * and the numbered substates
 *  - 0
 *  - 1
 *  - 2
 *  - 3
 *  - 4
 *
 * The substates and their meaning is explained in the function SYSCTRL_StateControl().
 */

#ifndef SYS_CONTROL_H_
#define SYS_CONTROL_H_

/*================== Includes =============================================*/
#include "syscontrol_cfg.h"


/*================== Macros and Definitions ===============================*/

/**
 * Symbolic names for busyness of the syscontrol
 */
typedef enum {
    SYSCTRL_CHECK_OK        = 0,    /*!< syscontrol ok      */
    SYSCTRL_CHECK_BUSY      = 1,    /*!< syscontrol busy    */
    SYSCTRL_CHECK_NOT_OK    = 2,    /*!< syscontrol not ok  */
} SYSCTRL_CHECK_e;



typedef enum {
  SYS_MODE_STARTUP_EVENT    = 0,    /*!< syscontrol startup                 */
// SYS_MODE_EVENT_INIT      = 1,    /*!< todo                               */
  SYS_MODE_CYCLIC_EVENT     = 2,    /*!< for cyclic events                  */
  SYS_MODE_TRIGGERED_EVENT  = 3,    /*!< for triggered events               */
  SYS_MODE_ABNORMAL_EVENT   = 4,    /*!< for abnormal (error etc.) events   */
  SYS_MODE_EVENT_RESERVED   = 0xFF, /*!< do not use                         */
} SYSCTRL_TRIG_EVENT_e;
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

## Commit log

2017-02-01 Adding foxBMS documentation
    [foxbms_bms-interface_v1.00.csv, foxbms_bms-master_basic_v1.00.csv, foxbms_bms-master_extension_v1.00.csv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]
2017-02-03 Changelog =============================
    0.4.3
    ----------
    - Important: Changed contactor configuration order in the software to match the labels on the front
    - Contactor 0: CONT_PLUS_MAIN
    - Contactor 1: CONT_PLUS_PRECHARGE
    - Contactor 2: CONT_MINUS_MAIN
    - Fixed an bug which could cause an unintended closing of the contactors after recovering from error mode
    - Increased stack size for the engine tasks to avoid stack overflow in some special conditions
    - Added a note in the documentation to indicate the necessity to send a periodic CAN message to the BMS
    - Fixed DLC of CAN message for the current sensor measurement
    - Added checksum verification for the flashed binaries
    - Updated li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
    [foxBMS_BMS-Interface_V1.00.brd, foxBMS_BMS-Interface_V1.00.sch, foxBMS_BMS-Master_Basic_V1.00.brd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]
2017-02-03 Renamed files in hardware documentation to match lowercase guideline
    [foxbms_bms-interface_v1.00.brd, foxbms_bms-interface_v1.00.sch, foxbms_bms-master_basic_v1.00.brd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]
2017-02-07 Removed layout and schematic files from documentation as they have their own repository.
    [foxbms_bms-interface_v1.00.brd, foxbms_bms-interface_v1.00.csv, foxbms_bms-interface_v1.00.sch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]
2017-03-31 Fixed checksum tool chain: replaced hard coded addresses in *.c/*.h files with relative ones.
2017-04-28 Correction in documentation in part on current sensor configuration.
2017-08-29 - updated year in the copyright - updated CHANGELOG.md - fixed markdown in LICENSE.md - minor changes in code and code cleanup - rewrite of the "eeprom"-module and moved to "nvram" - wscripts updated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
    [adc.c, batterycell_cfg.h]
2017-09-11 - updated CHANGELOG.md - fixed LTC temperature bug: We fixed a bug in the ltc driver, leading to a non-functional temperature sensing for foxBMS Slave Hardware version 1.xx. The slave version is conf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
    [ltc.c]

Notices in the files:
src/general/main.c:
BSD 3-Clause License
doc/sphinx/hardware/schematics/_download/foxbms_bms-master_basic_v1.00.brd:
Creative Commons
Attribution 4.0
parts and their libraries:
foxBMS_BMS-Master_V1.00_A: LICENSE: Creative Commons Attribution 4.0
